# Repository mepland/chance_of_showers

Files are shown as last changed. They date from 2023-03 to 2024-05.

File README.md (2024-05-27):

# chance\_of\_showers
Matthew Epland, PhD

This project provides live water pressure measurements
via a web dashboard running on a Raspberry Pi,
logs the data, and creates time series forecasts of future water pressure.





































## Introduction
Living in a 5th floor walk up in NYC can save you on rent and gym memberships,
but runs the risk of leaving you high and dry when your water pressure gives out!
The pressure delivered from the city's water mains is
_[typically](https://cooperatornews.com/article/dispelling-myths-about-poor-water-pressure)_
sufficient to reach the 6th floor,
with higher buildings needing a booster pump and one of NYC's iconic rooftop
[water towers](https://www.amny.com/real-estate/water-towers-nyc-s-misunderstood-icons-1-6982696).
My building lacks a pump and water tower,
leaving my top floor apartment with _just barely_ satisfactory pressure,
as long as no other units are using water!
As you can see in the data below,
my daytime water pressure is all over the place.
After being stranded soapy and cold halfway through a shower one too many times,
I decided to use my data science and electronics skills to record
the time series of my apartment's hot water pressure
with the goal of forecasting future availability,
and hence `chance_of_showers` was born!

<div align="center">
  <video src="https://github.com/mepland/chance_of_showers/assets/4729931/f3b94d00-fa40-4b0b-8b95-1105d11e7acd"></video>
</div>

## Data Analysis Results
WIP

### Time Series Plots

Below is a sample of the pressure data collected in November 2023.
Clicking the links will open interactive plotly plots, please explore!

#### [Raw analog to digital converter (ADC) values](https://mepland.github.io/chance_of_showers/media/ana_outputs/mean_pressure_value_selected_data.html)

The data acquisition (DAQ) system saves the raw pressure data
from the analog to digital converter (ADC) as an integer between 0 and 65472.
Note that occasionally a water hammer will increase the pressure above its steady state value,
marked by the orange 100% reference line,
with a subsequent decay on the order of 10 minutes.
When water is flowing at the pressure sensor,
the data is shown with an open purple marker.
Using water reduces the pressure slightly under normal conditions,
and abruptly ends overpressure events.

#### [Normalized values](https://mepland.github.io/chance_of_showers/media/ana_outputs/mean_pressure_value_normalized_selected_data.html)

To clean the data before fitting any models,
I rescale the values to 0 and 1 between the steady state extrema.
Any values that are outside the normalization range are capped.

### Overall Pressure Distributions
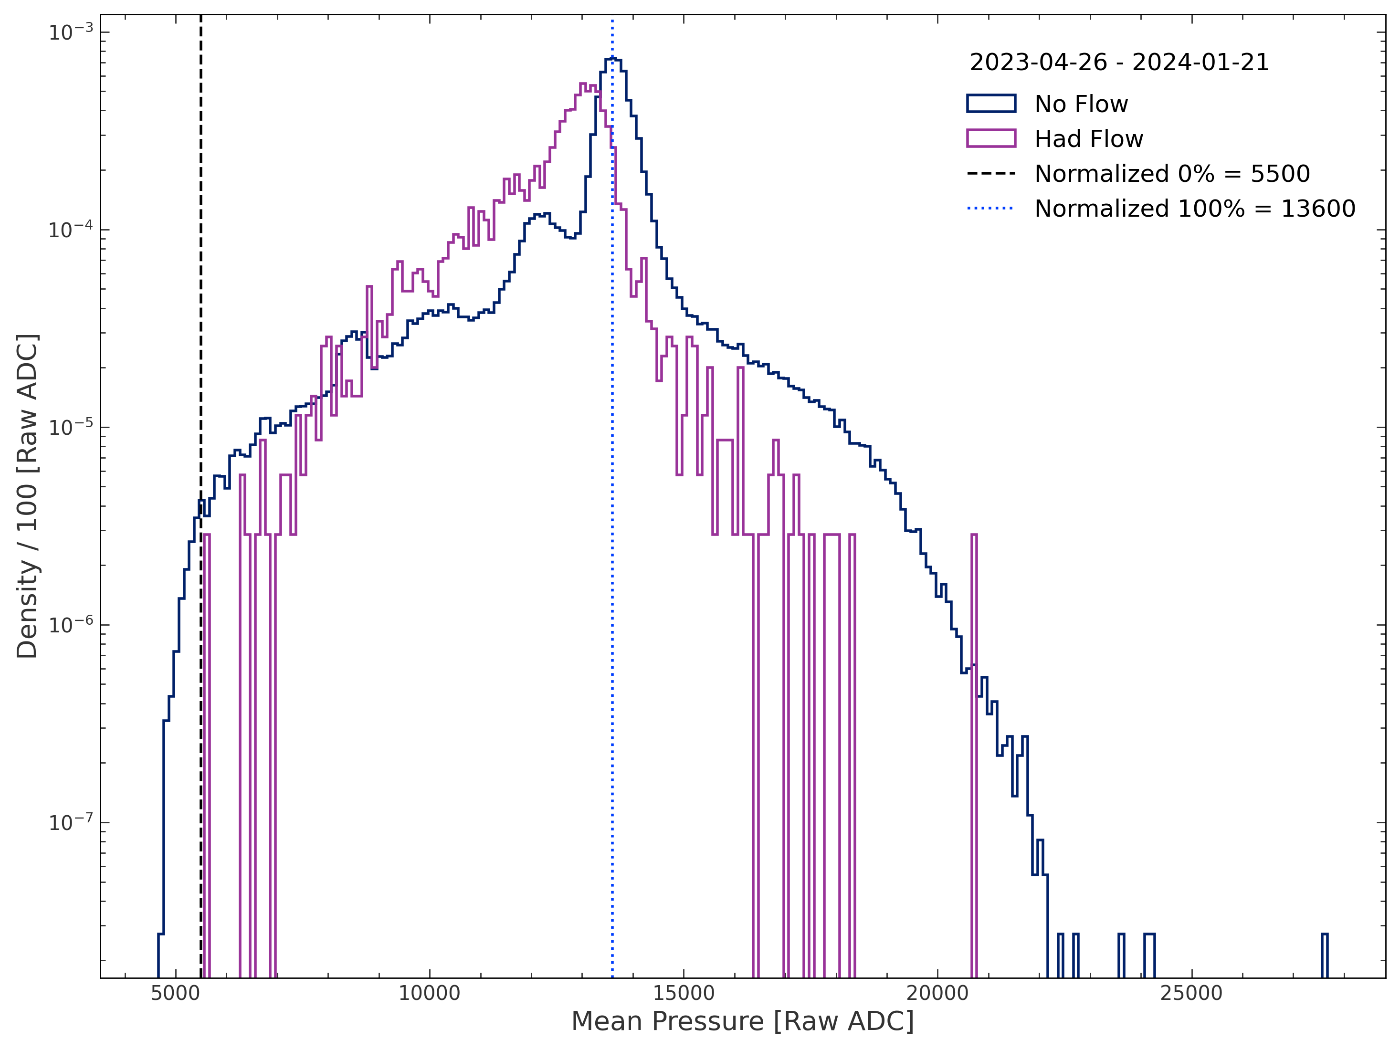
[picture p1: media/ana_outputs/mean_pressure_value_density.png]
Mean Pressure Value Density
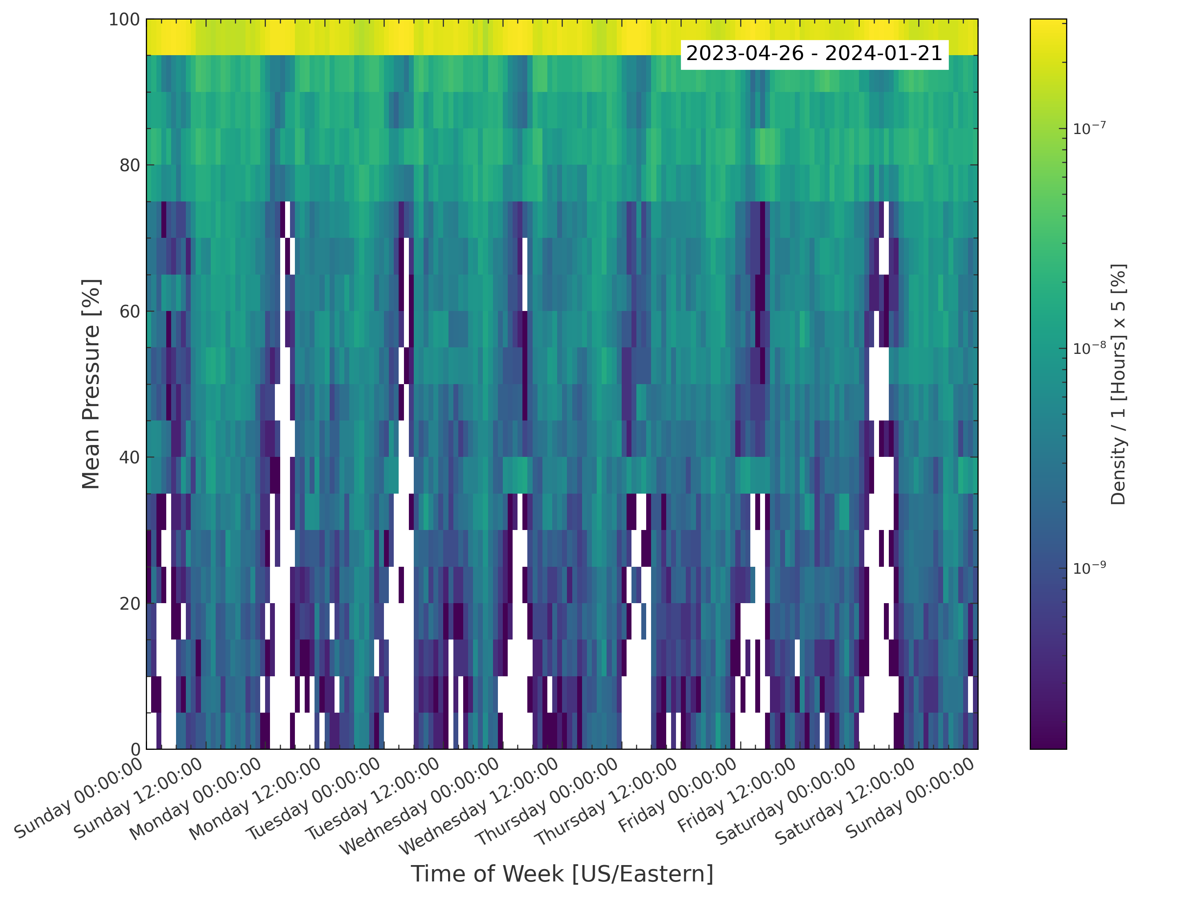
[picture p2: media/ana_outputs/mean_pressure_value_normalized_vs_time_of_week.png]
Mean Pressure Value Normalized vs Time of Week
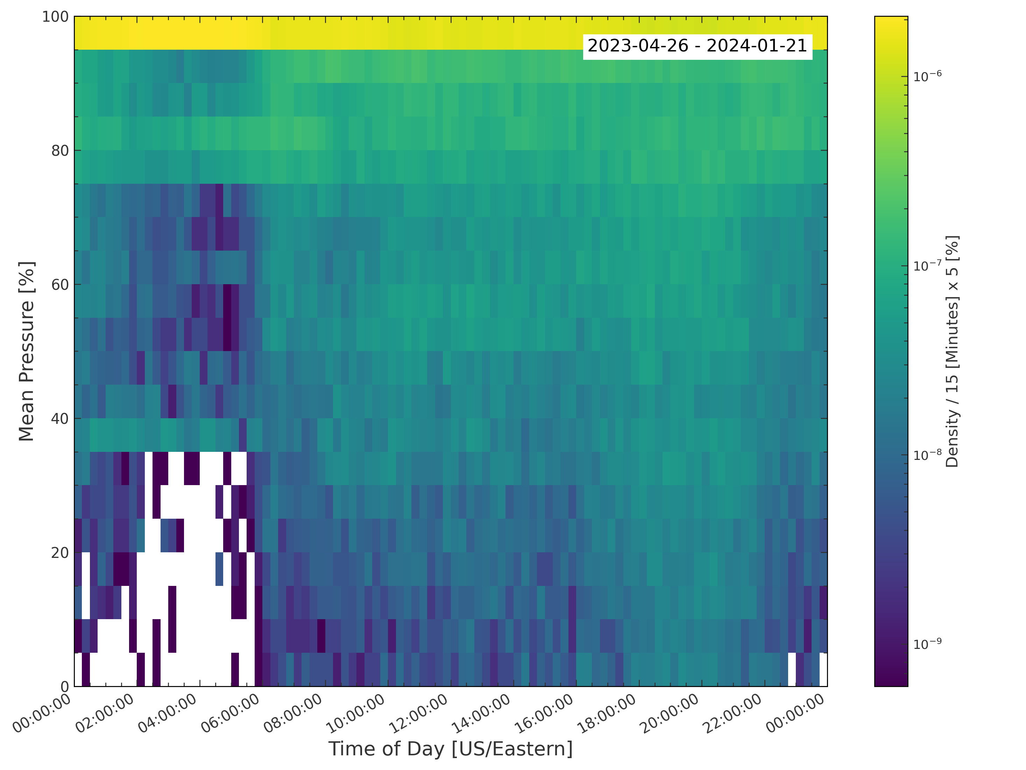
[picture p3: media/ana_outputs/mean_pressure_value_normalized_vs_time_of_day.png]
Mean Pressure Value Normalized vs Time of Day
|  |  |  |
| :---: | :---: | :---: |

### Prophet Results
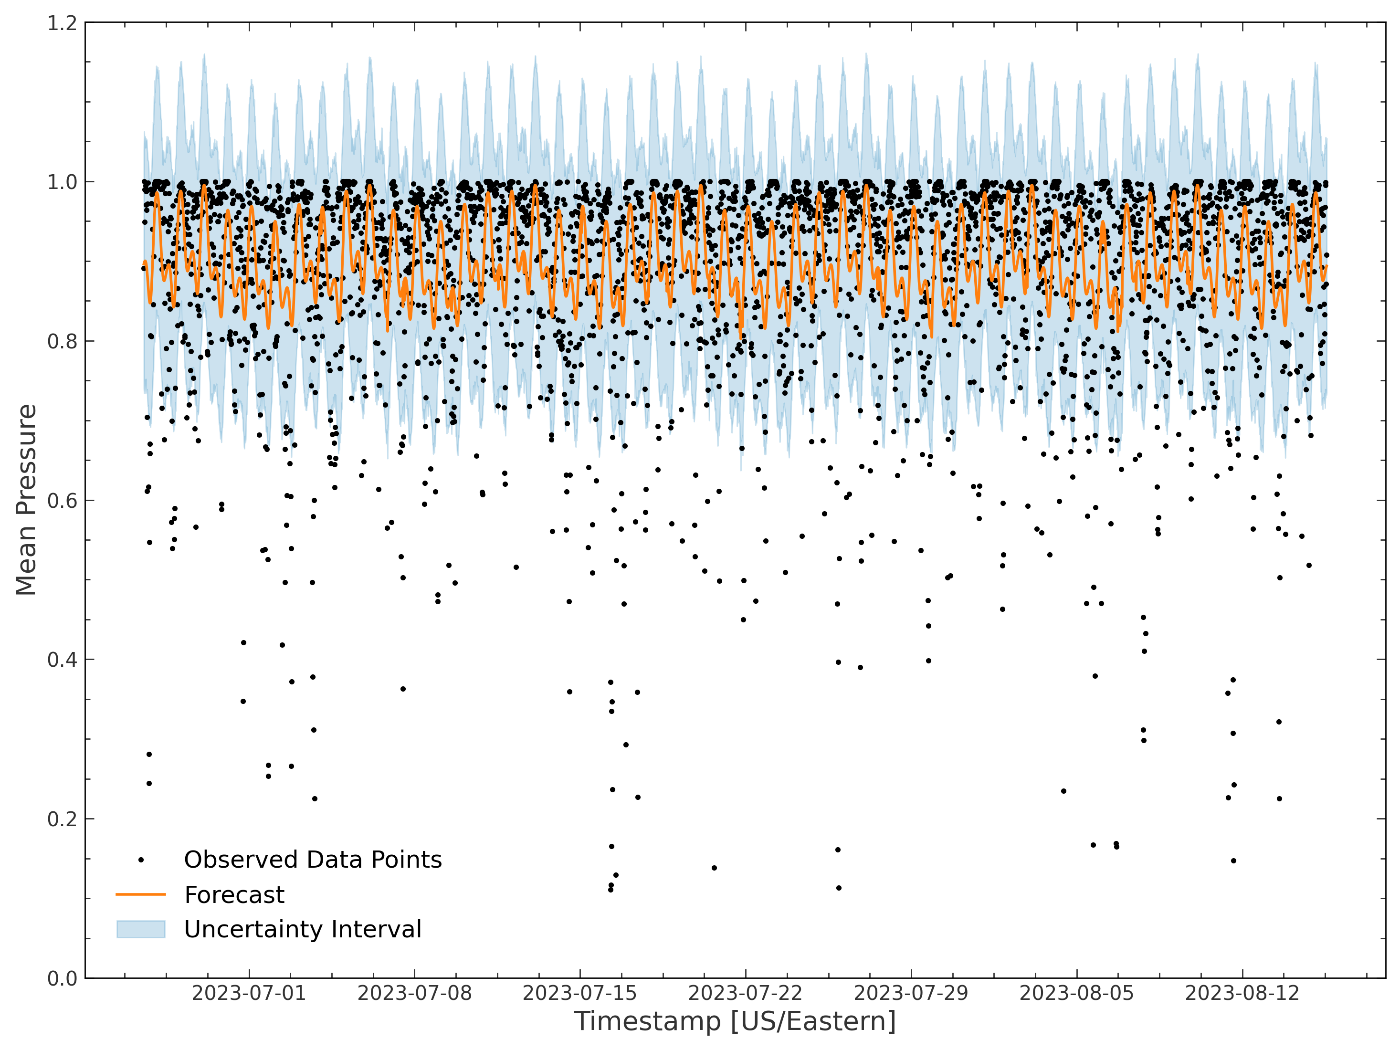
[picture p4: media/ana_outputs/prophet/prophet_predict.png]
Prophet Predict
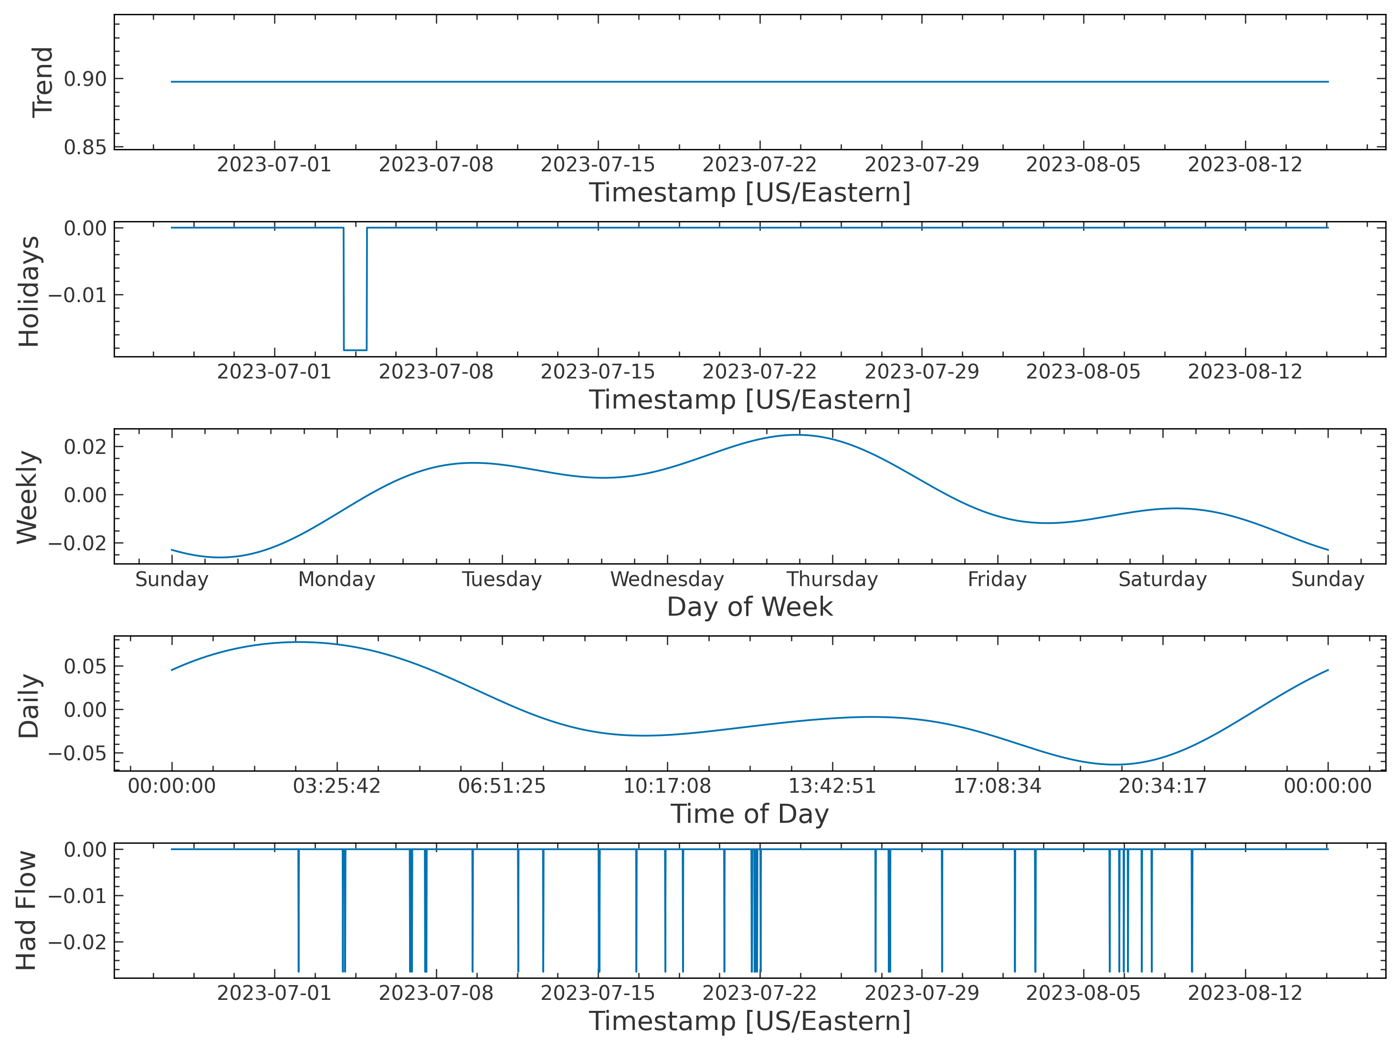
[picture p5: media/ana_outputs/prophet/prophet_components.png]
Prophet Components
|  |  |
| :---: | :---: |
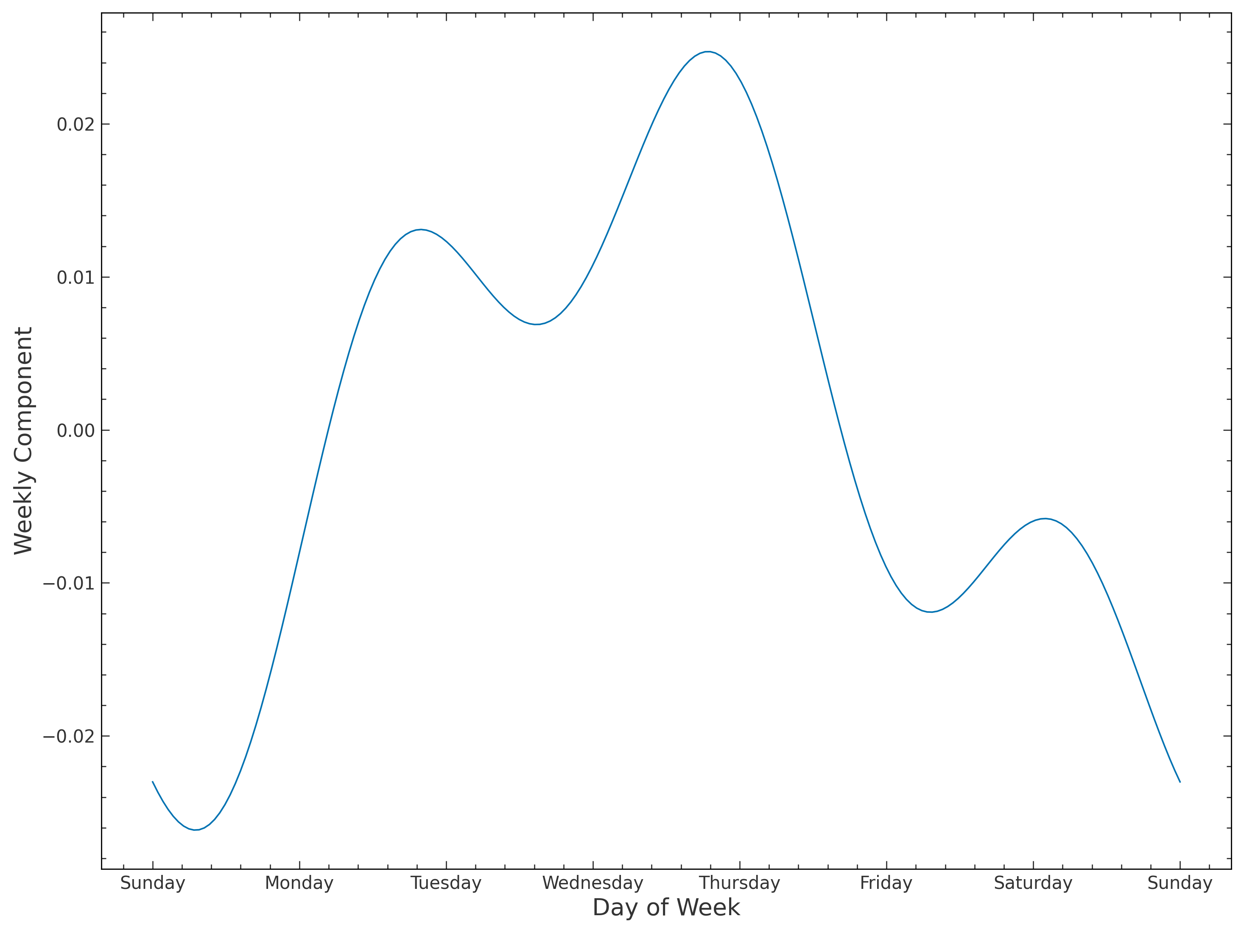
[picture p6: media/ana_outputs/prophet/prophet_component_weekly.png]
Prophet Components Weekly
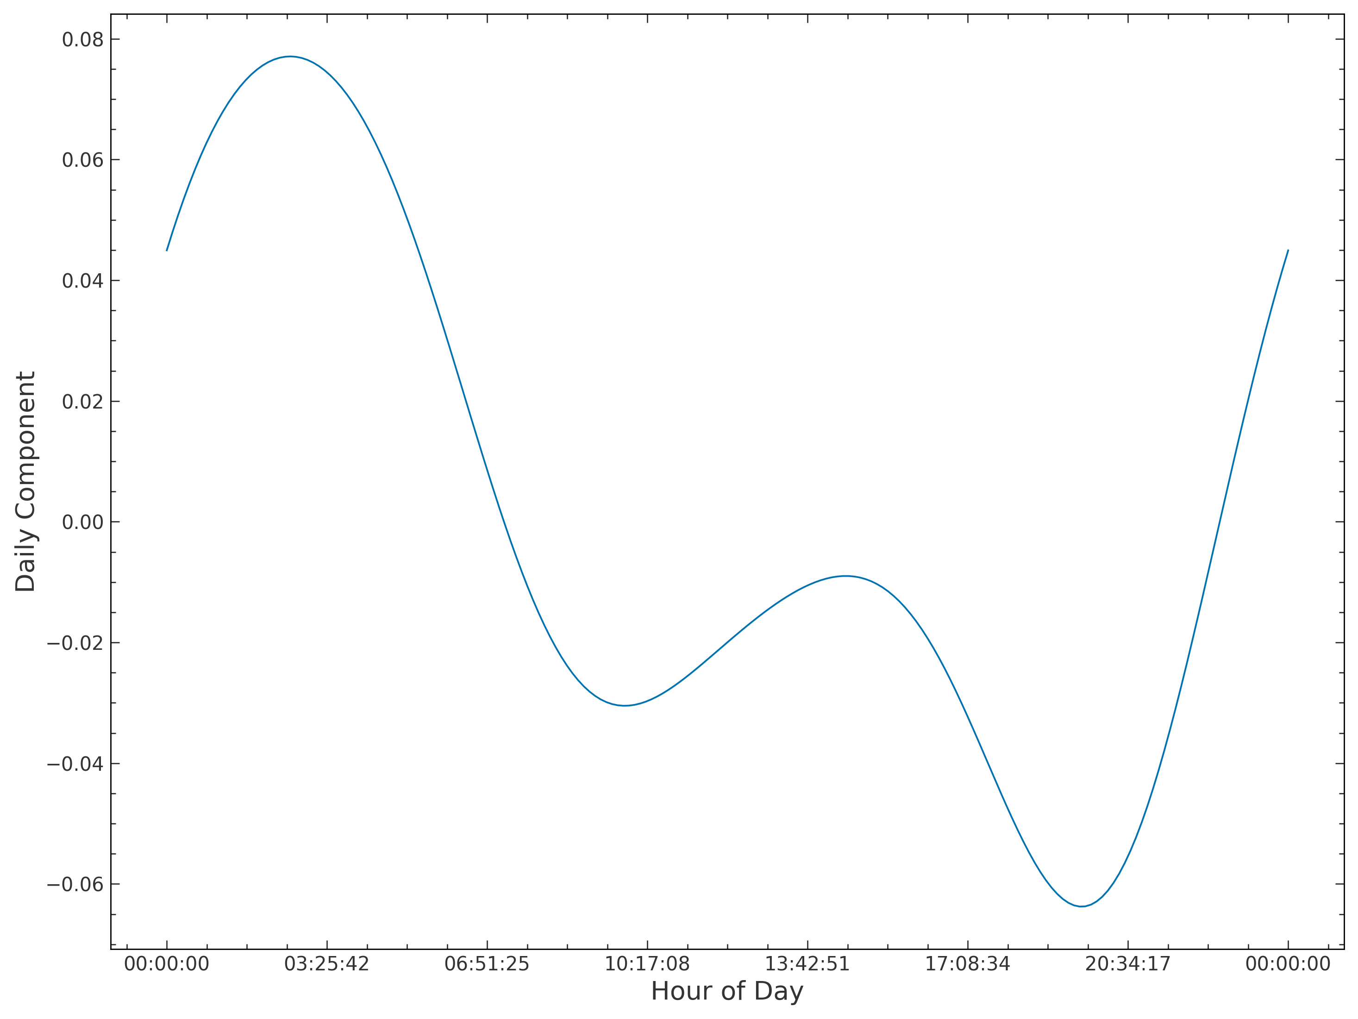
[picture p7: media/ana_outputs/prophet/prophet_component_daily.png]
Prophet Components Daily
|  |  |

## Hardware

### Bill of Materials
Here is a list of the components I used in my build.
With suitable alterations, the project could definitely be carried out with a wide array of other
sensors, single board computers or microcontrollers, plumbing supplies, etc.

#### Electronics

* [Raspberry Pi 4 Model B 2 GB](https://www.raspberrypi.com/products/raspberry-pi-4-model-b)
  * [USB C Power Supply](https://www.raspberrypi.com/products/type-c-power-supply)
  * [Micro SD Card](https://www.amazon.com/gp/product/B09TQS634Y)
* [8-Channel 10-Bit ADC with SPI Interface - MCP3008](https://www.digikey.com/en/products/detail/microchip-technology/MCP3008-I-P/319422)
* [DFRobot Gravity Water Pressure Sensor - SEN0257](https://wiki.dfrobot.com/Gravity__Water_Pressure_Sensor_SKU__SEN0257)
* [Water Flow Hall Effect Sensor Switch - YWBL-WH](https://www.amazon.com/Interface-Electromagnetic-Flowmeter-Industrial-Accessory/dp/B08B1NG4FZ)
* [1 kΩ and 10 kΩ Resistors](https://www.amazon.com/gp/product/B072BL2VX1)
* 830 Point Breadboard and Dupont Jumper Wires - [Included in GPIO Kit](https://www.amazon.com/gp/product/B08B4SHS18)

#### Plumbing

* [1/2" NPT 3 Way Tee Connector](https://www.amazon.com/Stainless-Diverter-Movable-Flexible-Connector/dp/B09MT39487)
* [Faucet Connector Hose, 3/8" Female Compression Thread to 1/2" Female NPT Thread - B1F09](https://www.amazon.com/gp/product/B000BQWNP8)
* [Adapter, 3/8" Male NPT to 1/2" Female NPT](https://www.amazon.com/gp/product/B07LD3GN4X/ref=ppx_od_dt_b_asin_title_s01)
* [Adapter, 1/2" Male NPT to G1/4" Female - ADT-N12M-G14F](https://koolance.com/threading-adapter-npt-1-2-male-to-g-1-4-female-adt-n12m-g14f)
* [PTFE (Teflon) Thread Seal Tape](https://www.amazon.com/DOPKUSS-Plumbers-Sealant-Waterproof-Inches/dp/B095YCMHNX)

#### Optional Components

* [I2C OLED Display](https://www.amazon.com/dp/B01MRR4LVE)
* [Geekworm Baseplate](https://www.amazon.com/gp/product/B07WCBXFD3)
* Wiring
  * [GPIO Extension Cable Kit](https://www.amazon.com/gp/product/B08B4SHS18)
  * [Breadboard Jumper Wires](https://www.amazon.com/gp/product/B07CJYSL2T)
  * [Clip to Dupont Jumper Wires](https://www.amazon.com/gp/product/B08M5GNY47)
* Cooling
  * [Heatsink - Geekworm P165-B](https://www.amazon.com/gp/product/B08N5VZN8R)
  * [Fan - Noctua NF-A4x20 5V PWM 4-Pin 40x20mm](https://www.amazon.com/gp/product/B071FNHVXN)
  * [2x20 Pin Header Kit](https://www.amazon.com/gp/product/B08GC18NMK) to clear heatsink
  * One [M3 Screw](https://www.amazon.com/gp/product/B01I74TTWU) to attach fan to heatsink
  * Four [M2.5 Screws](https://www.amazon.com/HELIFOUNER-Screws-Washers-Kit-Threaded/dp/B0BKSGC86F)
to attach heatsink to Pi and baseplate

### Circuit Diagram
The circuit diagram for this implementation
is provided as a [KiCad](https://www.kicad.org) schematic
[here](circuit_diagram/circuit_diagram.kicad_sch).

Circuit Diagram

### Photos
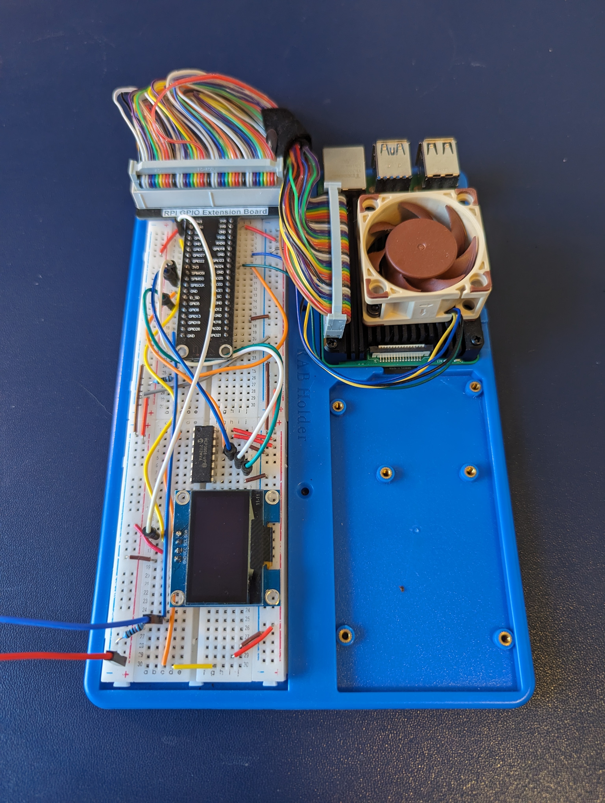
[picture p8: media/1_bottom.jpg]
Bottom
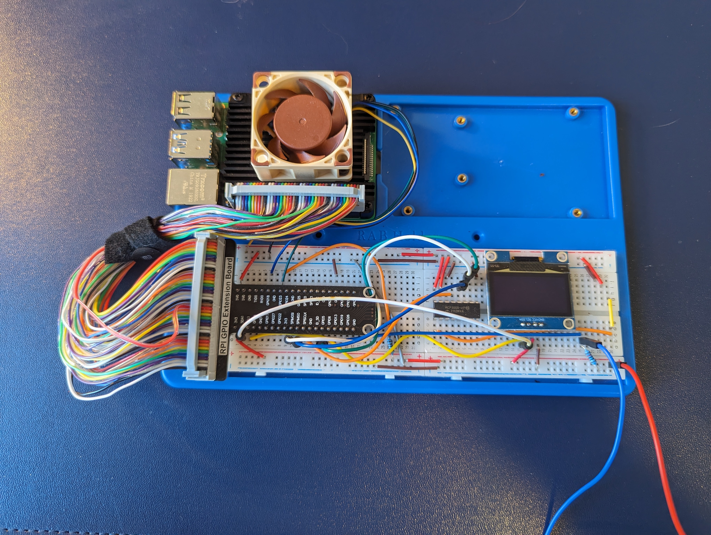
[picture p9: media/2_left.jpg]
Left
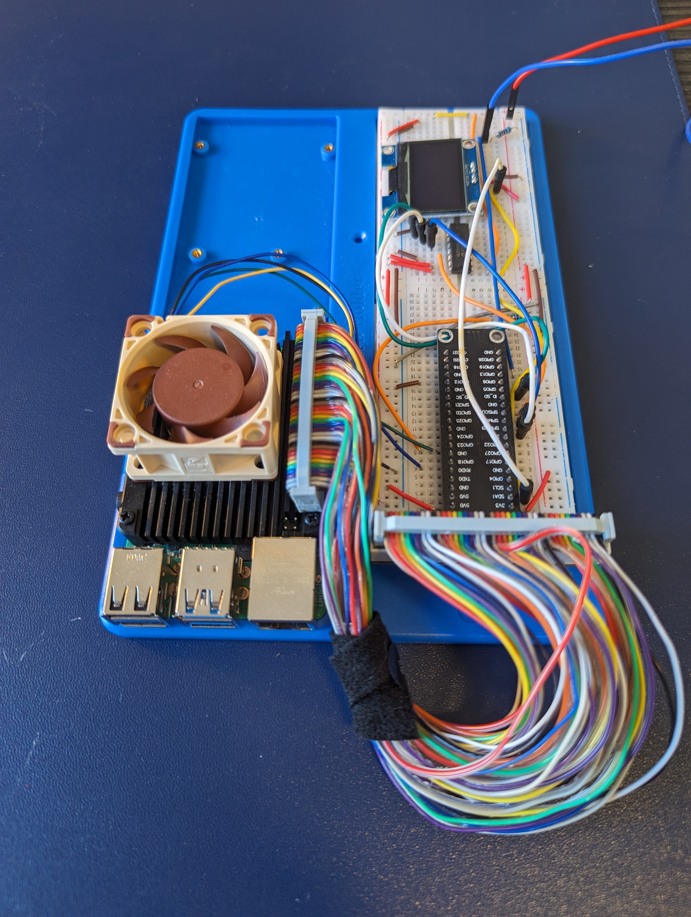
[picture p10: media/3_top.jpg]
Top
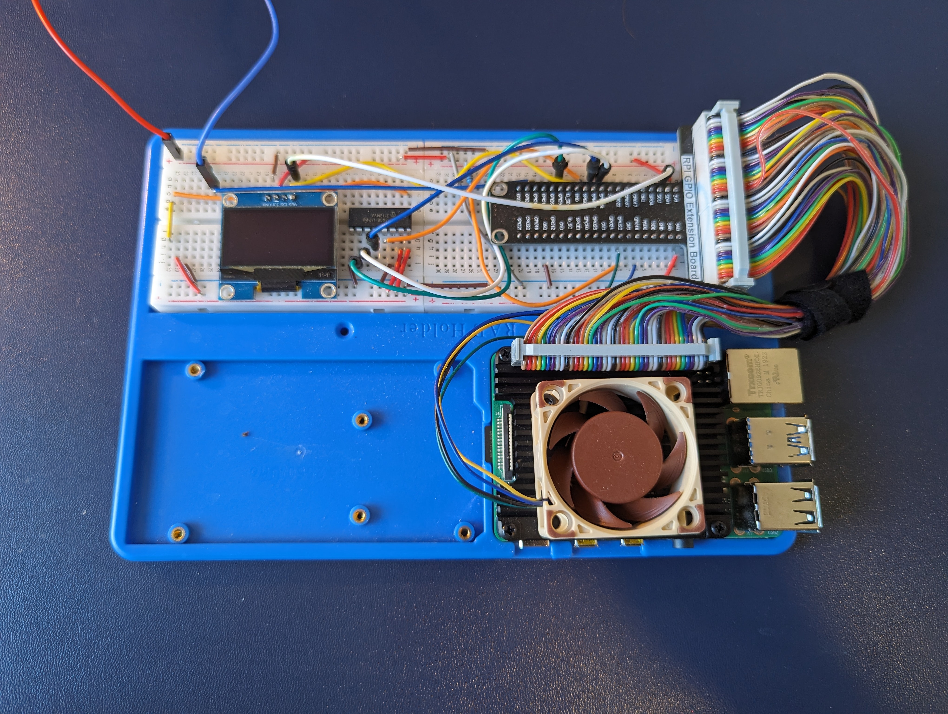
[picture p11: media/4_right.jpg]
Right
|  |  |  |  |
| :---: | :---: | :---: | :---: |
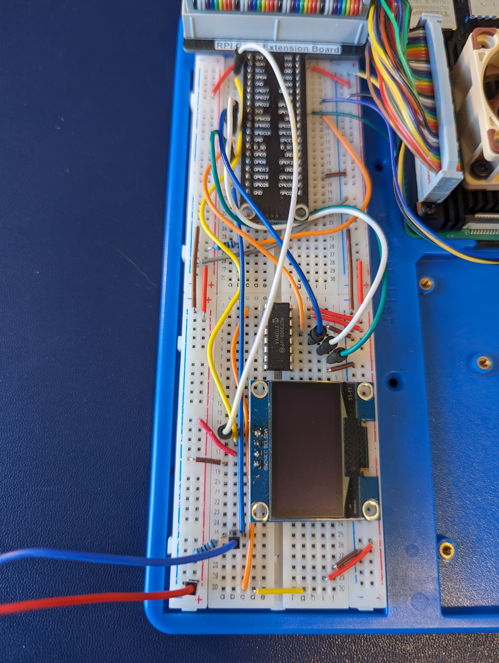
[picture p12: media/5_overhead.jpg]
Overhead
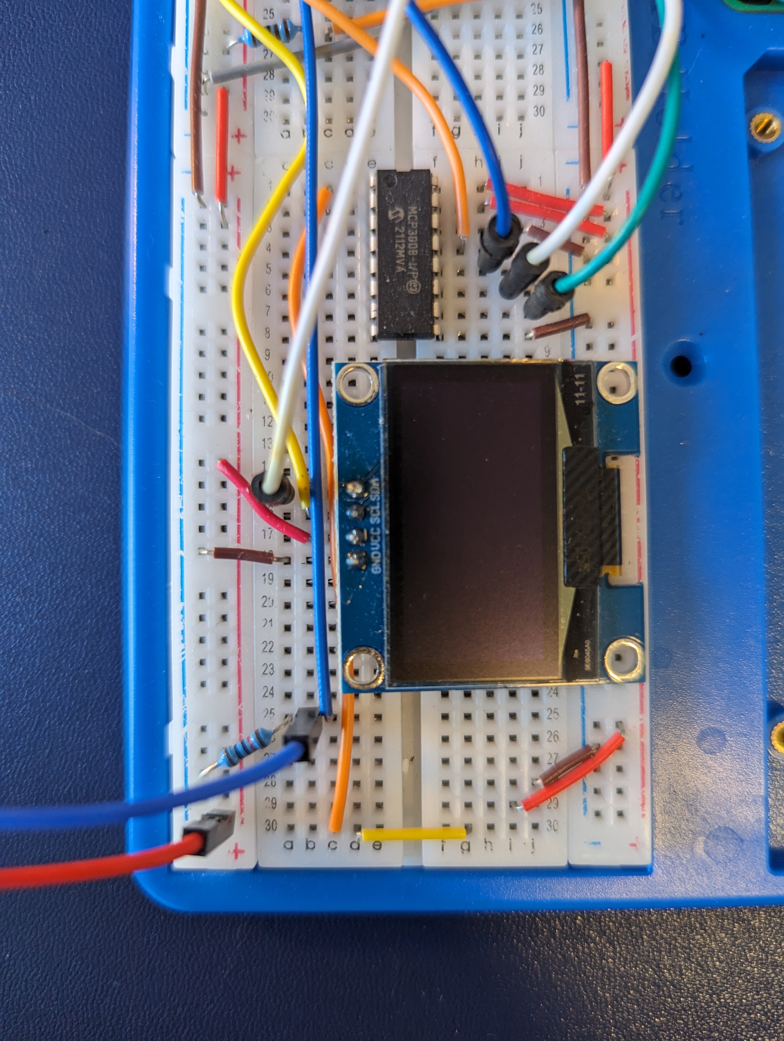
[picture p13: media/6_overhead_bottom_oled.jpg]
Overhead Bottom OLED
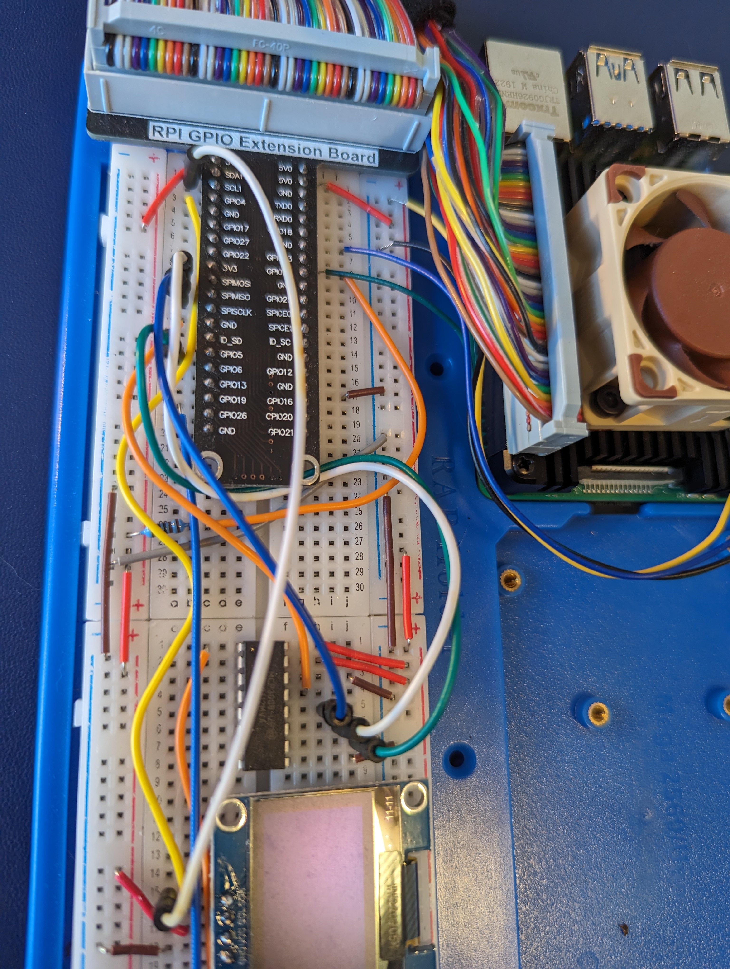
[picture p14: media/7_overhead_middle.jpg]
Overhead Middle
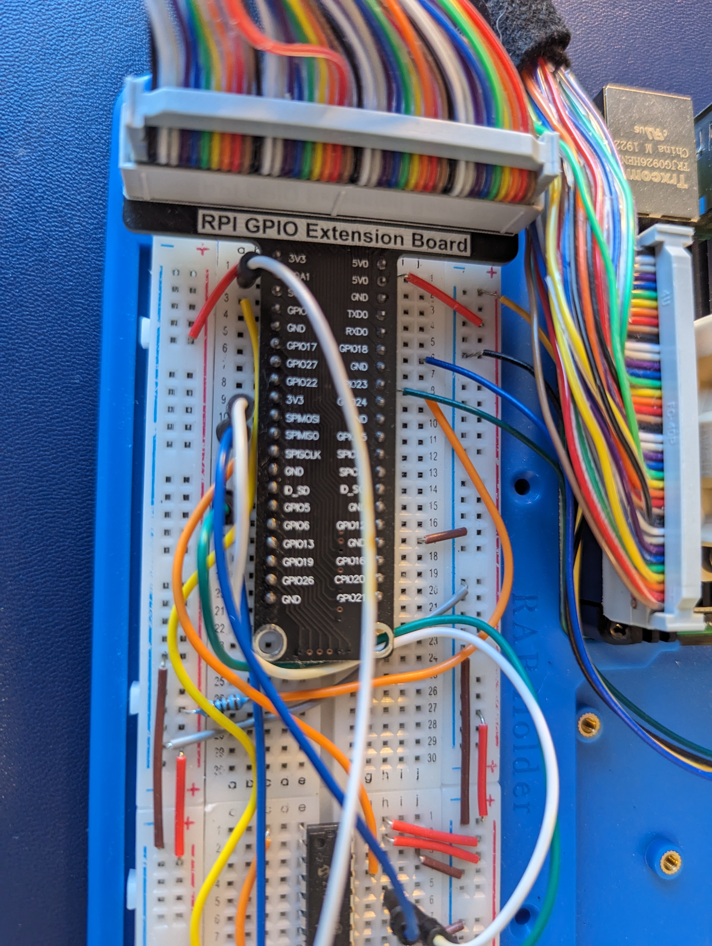
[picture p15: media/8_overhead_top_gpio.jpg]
Overhead Top GPIO
|  |  |  |  |
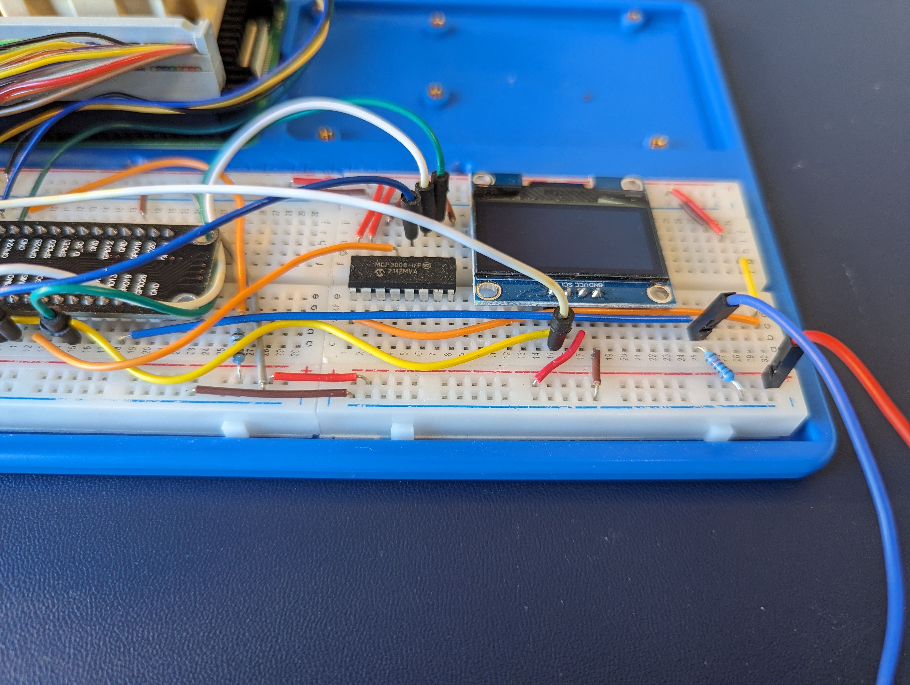
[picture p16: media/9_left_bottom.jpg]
Left Bottom
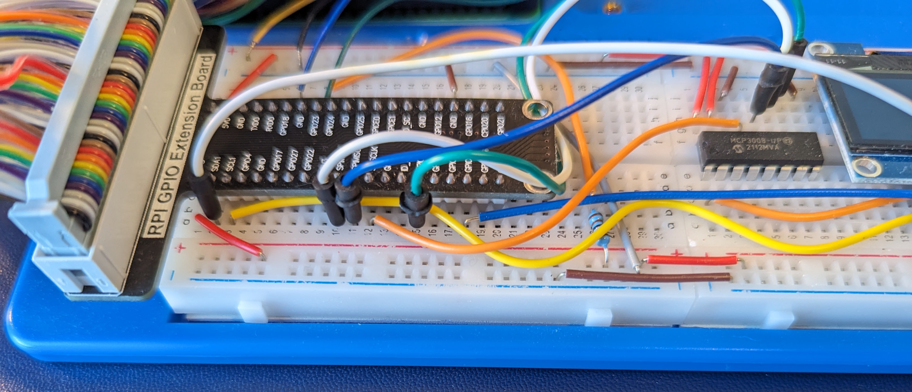
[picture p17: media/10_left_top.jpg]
Left Top
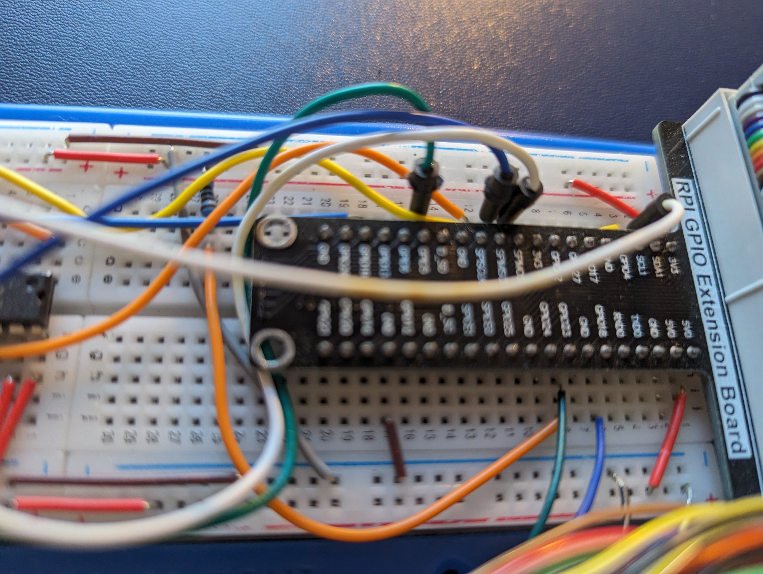
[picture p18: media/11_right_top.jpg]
Right Top
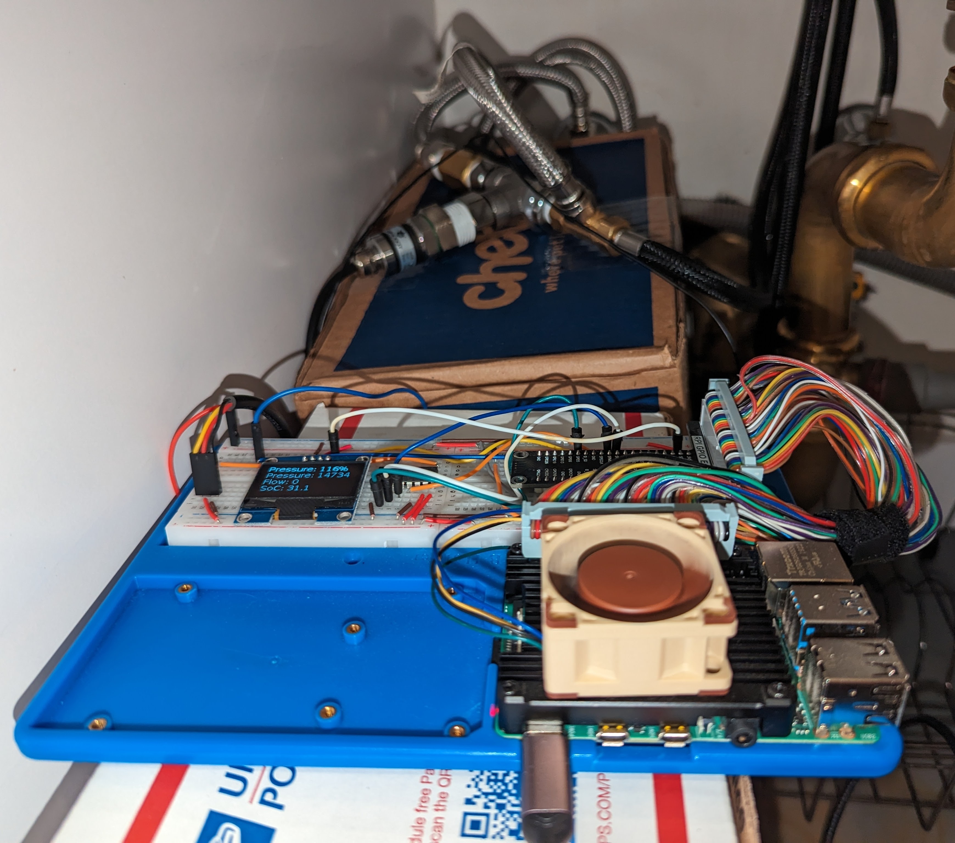
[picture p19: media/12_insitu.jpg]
In Situ
|  |  |  |  |
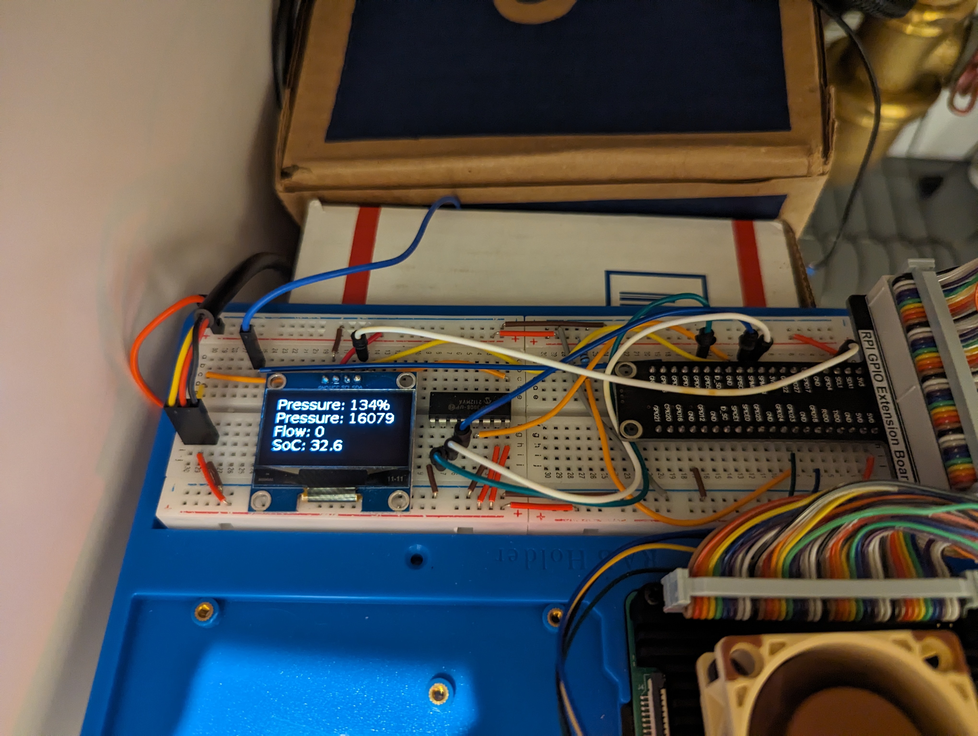
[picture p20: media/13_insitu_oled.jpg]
In Situ OLED
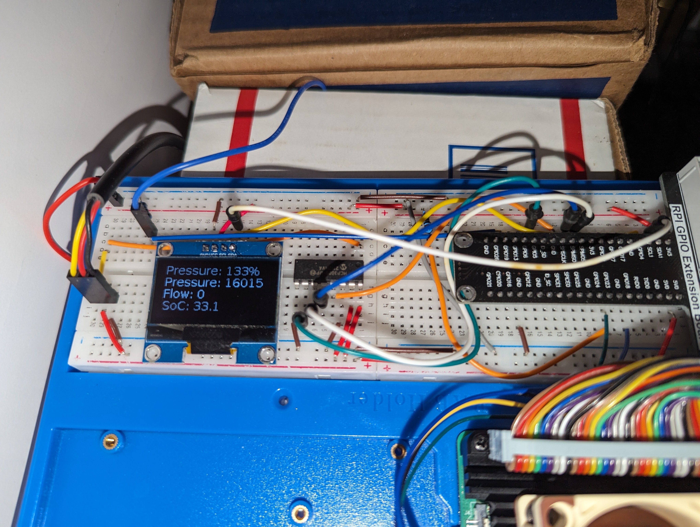
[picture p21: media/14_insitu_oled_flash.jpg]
In Situe OLED (Flash)
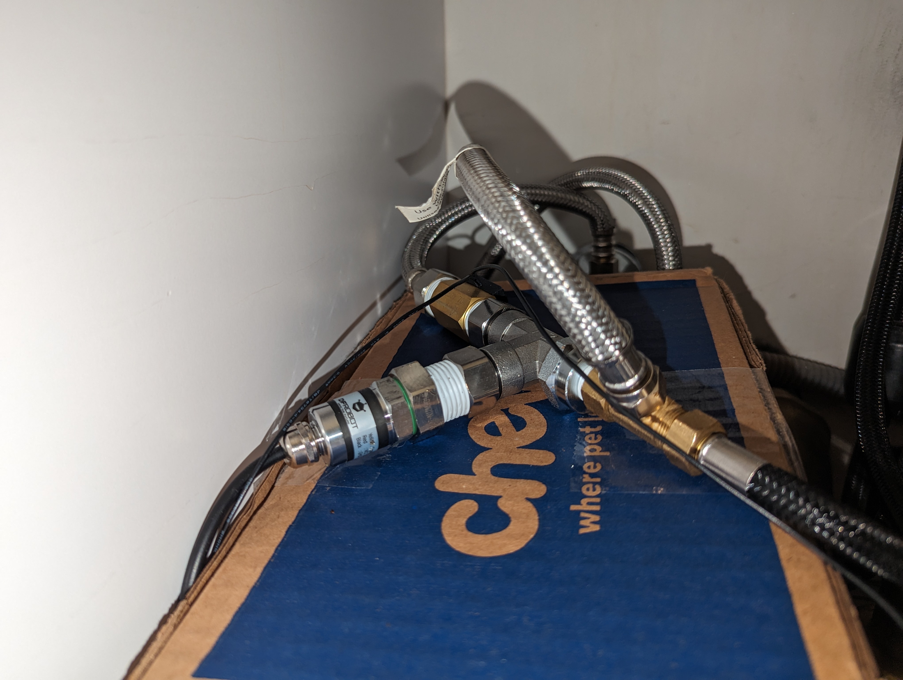
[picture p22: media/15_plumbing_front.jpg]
Plumbing Front
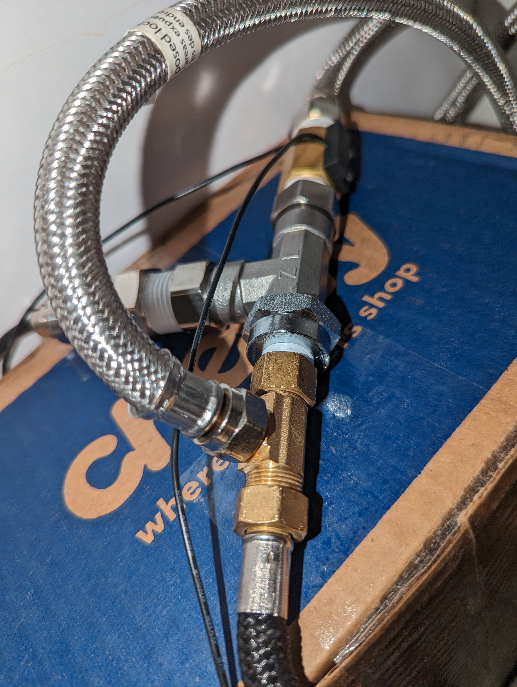
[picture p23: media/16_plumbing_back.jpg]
Plumbing Back
|  |  |  |  |

## Data Acquisition (DAQ)

The DAQ system recorded 95.4% of possible data points overall,
and 99.870% since implementing the cron job heartbeat monitoring.

### Launching the DAQ Script
The provided [`start_daq`](daq/start_daq) bash script
will start the [`daq.py`](daq/daq.py) and [`fan_control.py`](fan_control/fan_control.py)
scripts in new `tmux` windows.
You will need to update the `pkg_path` variable in `start_daq` per your installation location.

```bash
source daq/start_daq
```

### Opening the Web Dashboard
If `daq: {display_web: true}` is set in [`config.yaml`](config.yaml),
the local IP address and port of the dashboard will be logged on DAQ startup.
Open this link in your browser to see the live dashboard, as shown in the introduction.

### Setting up cron Jobs
Jobs to restart the DAQ on boot and every 30 minutes,
as well as send heartbeat API calls - see below,
are provided in the [`cron_jobs.txt`](daq/cron_jobs.txt) file.
Note that loading this file with `crontab` will overwrite **any** current cron jobs,
so check your existing settings first with `crontab -l`!

```bash
crontab -l

crontab daq/cron_jobs.txt
```

You can verify the cron jobs are running as expected with:

```bash
grep CRON /var/log/syslog | grep $LOGNAME
```

### Heartbeat Monitoring
You can use the provided [`heartbeat`](daq/heartbeat) bash script to send heartbeat API calls
for the DAQ script to [healthchecks.io](https://healthchecks.io) for monitoring and alerting.
[Configure your alert online at healthchecks.io](https://healthchecks.io/docs/configuring_checks),
and then run the below commands to setup a `secrets.json` file with your alert's `uuid`.
You will need to update the `pkg_path` variable in `heartbeat` per your installation location.
The provided `cron_jobs.txt` will setup a cron job
to send the heartbeat on the 15 and 45 minute of each hour.

```bash
sudo apt install -y jq
echo -e "{\n\t\"chance_of_showers_heartbeat_uuid\": \"YOUR_UUID_HERE\"\n}" > secrets.json
source daq/heartbeat
```

The `heartbeat` script has also been setup to backup
the `daq/raw_data` and `daq/saved_data` directories to
`backup_path="/media/usb_drive/daq_backup"`.
Please configure `backup_path` to fit your path, or comment out the `rsync` lines to turn them off.
Regular backups of the data to a separate drive are helpful as Raspberry Pis
have been known to corrupt their SD cards due to power loss or excessive writes.

### Combining Raw DAQ Files

Raw CSV files can be combined into convenient Parquet files
prior to analysis with the [`etl.py`](daq/etl.py) script.
If the script crashes, you may need to manually repair
any lines in the CSV files corrupted due to power losses.
Polars should generate error messages indicating
the corrupt datetime to help you locate the problematic file and line.

```bash
python daq/etl.py
```

## Bayesian Optimization

To optimize the many hyperparameters present in this project,
both of the individual forecasting models themselves as well as how the data is prepared,
[Bayesian optimization](https://github.com/mepland/data_science_notes)
was used to efficiently sample the parameter space.
The functions needed to run Bayesian optimization
are located in [`bayesian_opt.py`](utils/bayesian_opt.py),
and make use of the
[`bayesian-optimization`](https://github.com/bayesian-optimization/BayesianOptimization) library.

Unfortunately, actually running the optimization over GPU accelerated models
is not as simple as calling the `run_bayesian_opt()` function.
I have been unable to successfully detach the training of one GPU accelerated model
from the next when training multiple models in a loop.
The second training session will still have access to the tensors of the first,
leading to out of GPU memory errors, even when
[using commands like `gc.collect()` and `torch.cuda.empty_cache()`](https://stackoverflow.com/questions/70508960/how-to-free-gpu-memory-in-pytorch).
The `torch` models created by `darts` are very convenient,
but do not provide as much configurability as building your own `torch` model from scratch,
leaving me unable to fix this issue in a clean way.

To work around the GPU memory issues, a shell script,
[`start_bayesian_opt`](ana/start_bayesian_opt), is used to repeatedly call `run_bayesian_opt()`
via the [`bayesian_opt_runner.py`](ana/bayesian_opt_runner.py) script.
In this way each model is trained in its own Python session,
totally clearing memory between training iterations.
A signed pickle file is used to quickly load the necessary data and settings on each iteration.
Instructions for running the whole Bayesian optimization workflow are provided below.

Some hyperparameter points chosen for testing by the optimizer result in crashes during training,
either due to memory limitations, or invalid parameter combinations that slip by pre-run checks.
In most cases these exceptions can be caught within Python,
allowing the point to be automatically logged as having the worst possible `BAD_TARGET = -999.0`.
However, the Python process itself is occasionally killed
by the operating system with an uncatchable `SIGKILL` signal,
likely due to a request for too much memory.
Resuming the run will only result in repeated crashes on the same point as it is never written to disk.
Rather than rework the `bayesian-optimization` library to pre-register points before optimization,
a [`manual_bad_point.py`](ana/manual_bad_point.py) script is included
to easily log the few such points by hand.

### Running Bayesian Optimization

1. Create the input `parent_wrapper.pickle` file for `bayesian_opt_runner.py`
via the `exploratory_ana.py` notebook.
2. Configure the run in `start_bayesian_opt` and `bayesian_opt_runner.py`.
3. Run the shell script, logging outputs to disk via:
    * Log any bad points that are killed by the operating system
with `manual_bad_point.py` and resume the search.

```bash
./ana/start_bayesian_opt 2>&1 | tee ana/models/bayesian_optimization/bayesian_opt.log
```

## Dev Notes

### Data Analysis Setup - Installing CUDA and PyTorch

1. Find the supported CUDA version (`11.8.0`) for the current release of PyTorch (`2.0.1`) [here](https://pytorch.org/get-started/locally).
2. Install CUDA following the steps for the proper version and target platform [here](https://developer.nvidia.com/cuda-toolkit-archive).
3. Update the poetry `pytorch-gpu-src` source to point to the correct PyTorch version in [`pyproject.toml`](pyproject.toml).
    * This is in place of `pip install --index-url=...` as provided by the [PyTorch installation instructions](https://pytorch.org/get-started/locally).
4. Install the poetry `ana` group with `make setupANA`.
    * This will install `pytorch`, along with the other necessary packages.
5. Check that PyTorch and CUDA are correctly configured with the following `python` commands:

```python
import torch

if torch.cuda.is_available():
    print("CUDA is available")
    print(f"Device name: {torch.cuda.get_device_name(torch.cuda.current_device())}")
else:
    print("CUDA IS NOT AVAILABLE!")
```

### DAQ Setup - Installing Python 3.11 on Raspbian
If `python 3.11` is not available in your release of Raspbian,
you can compile it from source following the instructions [here](https://aruljohn.com/blog/python-raspberrypi),
but will also need to [install the sqlite extensions](https://stackoverflow.com/a/24449632):

<!-- markdownlint-disable MD013 -->
```bash
cd /usr/src/
sudo wget https://www.python.org/ftp/python/3.11.4/Python-3.11.4.tgz
sudo tar -xzvf Python-3.11.4.tgz
cd Python-3.11.4/
sudo apt update && sudo apt full-upgrade -y
sudo apt install -y build-essential libbz2-dev libc6-dev libexpat1-dev libffi-dev libgdbm-dev liblzma-dev libncurses5-dev libnss3-dev libsqlite3-dev libssl-dev lzma pkg-config zlib1g-dev
sudo apt autoremove -y
sudo apt update && sudo apt full-upgrade -y
./configure --enable-optimizations --enable-loadable-sqlite-extensions
sudo make altinstall

# Should be Python 3.11.4 with your compile info
/usr/local/bin/python3.11 -VV

# Link binary
sudo rm /usr/bin/python
sudo rm /usr/bin/python3
sudo ln -s /usr/local/bin/python3.11 /usr/bin/python
sudo ln -s /usr/local/bin/python3.11 /usr/bin/python3

# Should match /usr/local/bin/python3.11 -VV
python -VV
```

#### Additional DAQ Dependencies
To finish setting up the DAQ system you must also:

* Install `tmux`, which is not included in Raspbian by default.
`tmux` is used to control multiple terminal sessions in [`start_daq`](daq/start_daq).
* Install `pigpio`, which is not included in Raspbian Lite, i.e. headless, installations.
`pigpio` is necessary to interface with the GPIO ports and must also be enabled via a [daemon](https://gpiozero.readthedocs.io/en/latest/remote_gpio.html)
* Enable SPI, I2C, and Remote GPIO via `raspi-config`.
* Prevent the [WiFi from powering off](https://desertbot.io/blog/headless-raspberry-pi-4-ssh-wifi-setup-64-bit-mac-windows).
* It is recommended to [install](https://pimylifeup.com/raspberry-pi-log2ram) [`log2ram`](https://github.com/azlux/log2ram) to avoid unnecessary writes to the SD card, prolonging the card's lifetime.

```bash
# Install tmux and pigpio
sudo apt-get install -y tmux pigpio

# Enable SPI, I2C, and Remote GPIO
sudo raspi-config

# Setup pigpio daemon
sudo systemctl enable pigpiod

# Prevent the WiFi from powering off
# Above the line that says exit 0 insert `/sbin/iw wlan0 set power_save off` and save the file
sudo vi /etc/rc.local

# Install log2ram
echo "deb [signed-by=/usr/share/keyrings/azlux-archive-keyring.gpg] http://packages.azlux.fr/debian/ bullseye main" | sudo tee /etc/apt/sources.list.d/azlux.list
sudo wget -O /usr/share/keyrings/azlux-archive-keyring.gpg https://azlux.fr/repo.gpg
sudo apt update && sudo apt full-upgrade -y
sudo apt install -y log2ram
```
<!-- markdownlint-enable MD013 -->

### Installing Dependencies with Poetry
Install `poetry` following the [instructions here](https://python-poetry.org/docs#installation).

```bash
curl -sSL https://install.python-poetry.org | python3 -
```

Then install the `python` packages needed for this installation. Groups include:

* `daq` for packages needed to run the DAQ script on a Raspberry Pi, optional
* `web` for packages needed to run the live dashboard from the DAQ script, optional
* `ana` for analysis tools, optional
* `dev` for continuous integration (CI) and linting tools

```bash
poetry install --with daq,web
```

or

```bash
poetry install --with ana
```

### Setting up pre-commit
It is recommended to use the [`pre-commit`](https://pre-commit.com) tool
to automatically check your commits locally as they are created.
You should just need to [install the git hook scripts](https://pre-commit.com/#3-install-the-git-hook-scripts),
see below, after installing the `dev` dependencies.
This will run the checks in [`.pre-commit-config.yaml`](.pre-commit-config.yaml)
when you create a new commit.

```bash
pre-commit install
```

### Installing Non-Python Based Linters
Markdown is linted using [`markdownlint-cli`](https://github.com/igorshubovych/markdownlint-cli),
JavaScript by [`standard`](https://github.com/standard/standard),
and HTML, SCSS, CSS, and TOML by [`prettier`](https://prettier.io).
You can install these JavaScript-based linters globally with:

```bash
sudo npm install --global markdownlint-cli standard prettier
sudo npm install --global --save-dev --save-exact prettier-plugin-toml
```

Shell files are linted using [`shellcheck`](https://github.com/koalaman/shellcheck)
and [`shfmt`](https://github.com/mvdan/sh).
Follow the linked installation instructions for your system.
On Fedora they are:

```bash
sudo dnf install ShellCheck shfmt
```

### Using the Makefile
A [`Makefile`](Makefile) is provided for convenience,
with commands to setup the DAQ and analysis environments,
`make setupDAQ` and `make setupANA`,
as well run CI and linting tools,
e.g. `make black`, `make pylint`, `make pre-commit`.

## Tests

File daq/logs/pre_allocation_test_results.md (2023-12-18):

# DAQ Pre-allocation Tests
Below are the tails of log files for complete weeks, without any web logging messages.

## Pre-allocated Results
`daq_2023-11-12-05-00-16.log` and prior use pre-allocated array variables, and have less memory usage.

<!-- markdownlint-disable MD013 -->
```bash
==> daq_2023-10-01-04-00-16.log <==
2023-10-07 23:01:00 UTC [daq     ] [Thread-6 (] [INFO    ] RAM Available: 1.7 GB, Used: 229.7 MB, Percent: 15.80%
2023-10-07 23:31:00 UTC [daq     ] [Thread-6 (] [INFO    ] RAM Available: 1.7 GB, Used: 229.6 MB, Percent: 15.80%
2023-10-08 00:01:00 UTC [daq     ] [Thread-6 (] [INFO    ] RAM Available: 1.7 GB, Used: 229.5 MB, Percent: 15.80%
2023-10-08 00:31:00 UTC [daq     ] [Thread-6 (] [INFO    ] RAM Available: 1.7 GB, Used: 230.6 MB, Percent: 15.80%
2023-10-08 01:01:00 UTC [daq     ] [Thread-6 (] [INFO    ] RAM Available: 1.7 GB, Used: 231.1 MB, Percent: 15.90%
2023-10-08 01:31:00 UTC [daq     ] [Thread-6 (] [INFO    ] RAM Available: 1.7 GB, Used: 231.0 MB, Percent: 15.90%
2023-10-08 02:01:00 UTC [daq     ] [Thread-6 (] [INFO    ] RAM Available: 1.7 GB, Used: 230.8 MB, Percent: 15.80%
2023-10-08 02:31:00 UTC [daq     ] [Thread-6 (] [INFO    ] RAM Available: 1.7 GB, Used: 231.0 MB, Percent: 15.90%
2023-10-08 03:01:00 UTC [daq     ] [Thread-6 (] [INFO    ] RAM Available: 1.7 GB, Used: 231.6 MB, Percent: 15.90%
2023-10-08 03:31:00 UTC [daq     ] [Thread-6 (] [INFO    ] RAM Available: 1.7 GB, Used: 230.7 MB, Percent: 15.80%

==> daq_2023-10-08-04-00-16.log <==
2023-10-14 23:01:00 UTC [daq     ] [Thread-6 (] [INFO    ] RAM Available: 1.7 GB, Used: 228.1 MB, Percent: 15.70%
2023-10-14 23:31:00 UTC [daq     ] [Thread-6 (] [INFO    ] RAM Available: 1.7 GB, Used: 230.2 MB, Percent: 15.80%
2023-10-15 00:01:00 UTC [daq     ] [Thread-6 (] [INFO    ] RAM Available: 1.7 GB, Used: 228.6 MB, Percent: 15.70%
2023-10-15 00:31:00 UTC [daq     ] [Thread-6 (] [INFO    ] RAM Available: 1.7 GB, Used: 229.4 MB, Percent: 15.80%
2023-10-15 01:01:00 UTC [daq     ] [Thread-6 (] [INFO    ] RAM Available: 1.7 GB, Used: 228.4 MB, Percent: 15.70%
2023-10-15 01:31:00 UTC [daq     ] [Thread-6 (] [INFO    ] RAM Available: 1.7 GB, Used: 229.9 MB, Percent: 15.80%
2023-10-15 02:01:00 UTC [daq     ] [Thread-6 (] [INFO    ] RAM Available: 1.7 GB, Used: 229.6 MB, Percent: 15.80%
2023-10-15 02:31:00 UTC [daq     ] [Thread-6 (] [INFO    ] RAM Available: 1.7 GB, Used: 229.8 MB, Percent: 15.80%
2023-10-15 03:01:00 UTC [daq     ] [Thread-6 (] [INFO    ] RAM Available: 1.7 GB, Used: 229.6 MB, Percent: 15.80%
2023-10-15 03:31:00 UTC [daq     ] [Thread-6 (] [INFO    ] RAM Available: 1.7 GB, Used: 231.4 MB, Percent: 15.90%

==> daq_2023-10-22-04-00-16.log <==
2023-10-28 23:01:00 UTC [daq     ] [Thread-6 (] [INFO    ] RAM Available: 1.7 GB, Used: 232.0 MB, Percent: 15.90%
2023-10-28 23:31:00 UTC [daq     ] [Thread-6 (] [INFO    ] RAM Available: 1.7 GB, Used: 230.3 MB, Percent: 15.80%
2023-10-29 00:01:00 UTC [daq     ] [Thread-6 (] [INFO    ] RAM Available: 1.7 GB, Used: 233.0 MB, Percent: 16.00%
2023-10-29 00:31:00 UTC [daq     ] [Thread-6 (] [INFO    ] RAM Available: 1.7 GB, Used: 231.9 MB, Percent: 15.90%
2023-10-29 01:01:00 UTC [daq     ] [Thread-6 (] [INFO    ] RAM Available: 1.7 GB, Used: 231.6 MB, Percent: 15.90%
2023-10-29 01:31:00 UTC [daq     ] [Thread-6 (] [INFO    ] RAM Available: 1.7 GB, Used: 233.3 MB, Percent: 16.00%
2023-10-29 02:01:00 UTC [daq     ] [Thread-6 (] [INFO    ] RAM Available: 1.7 GB, Used: 233.1 MB, Percent: 16.00%
2023-10-29 02:31:00 UTC [daq     ] [Thread-6 (] [INFO    ] RAM Available: 1.7 GB, Used: 233.6 MB, Percent: 16.00%
2023-10-29 03:01:00 UTC [daq     ] [Thread-6 (] [INFO    ] RAM Available: 1.7 GB, Used: 233.6 MB, Percent: 16.00%
2023-10-29 03:31:00 UTC [daq     ] [Thread-6 (] [INFO    ] RAM Available: 1.7 GB, Used: 234.1 MB, Percent: 16.00%

==> daq_2023-10-29-04-00-16.log <==
2023-11-04 17:31:00 UTC [daq     ] [Thread-6 (] [INFO    ] RAM Available: 1.7 GB, Used: 228.1 MB, Percent: 15.70%
2023-11-04 18:01:00 UTC [daq     ] [Thread-6 (] [INFO    ] RAM Available: 1.7 GB, Used: 228.1 MB, Percent: 15.70%
2023-11-04 18:31:00 UTC [daq     ] [Thread-6 (] [INFO    ] RAM Available: 1.7 GB, Used: 228.4 MB, Percent: 15.70%
2023-11-04 19:01:00 UTC [daq     ] [Thread-6 (] [INFO    ] RAM Available: 1.7 GB, Used: 228.4 MB, Percent: 15.70%
2023-11-04 19:31:00 UTC [daq     ] [Thread-6 (] [INFO    ] RAM Available: 1.7 GB, Used: 230.9 MB, Percent: 15.80%
2023-11-04 20:01:00 UTC [daq     ] [Thread-6 (] [INFO    ] RAM Available: 1.7 GB, Used: 229.4 MB, Percent: 15.80%
2023-11-04 20:31:00 UTC [daq     ] [Thread-6 (] [INFO    ] RAM Available: 1.7 GB, Used: 228.8 MB, Percent: 15.70%
2023-11-04 21:01:00 UTC [daq     ] [Thread-6 (] [INFO    ] RAM Available: 1.7 GB, Used: 230.3 MB, Percent: 15.80%
2023-11-04 21:31:00 UTC [daq     ] [Thread-6 (] [INFO    ] RAM Available: 1.7 GB, Used: 229.0 MB, Percent: 15.70%
2023-11-04 22:01:00 UTC [daq     ] [Thread-6 (] [INFO    ] RAM Available: 1.7 GB, Used: 231.1 MB, Percent: 15.90%

==> daq_2023-11-05-04-00-16.log <==
2023-11-12 00:01:00 UTC [daq     ] [Thread-6 (] [INFO    ] RAM Available: 1.7 GB, Used: 232.7 MB, Percent: 15.90%
2023-11-12 00:31:00 UTC [daq     ] [Thread-6 (] [INFO    ] RAM Available: 1.7 GB, Used: 232.2 MB, Percent: 15.90%
2023-11-12 01:01:00 UTC [daq     ] [Thread-6 (] [INFO    ] RAM Available: 1.7 GB, Used: 233.7 MB, Percent: 16.00%
2023-11-12 01:31:00 UTC [daq     ] [Thread-6 (] [INFO    ] RAM Available: 1.7 GB, Used: 233.8 MB, Percent: 16.00%
2023-11-12 02:01:00 UTC [daq     ] [Thread-6 (] [INFO    ] RAM Available: 1.7 GB, Used: 232.7 MB, Percent: 15.90%
2023-11-12 02:31:00 UTC [daq     ] [Thread-6 (] [INFO    ] RAM Available: 1.7 GB, Used: 233.9 MB, Percent: 16.00%
2023-11-12 03:01:00 UTC [daq     ] [Thread-6 (] [INFO    ] RAM Available: 1.7 GB, Used: 232.9 MB, Percent: 15.90%
2023-11-12 03:31:00 UTC [daq     ] [Thread-6 (] [INFO    ] RAM Available: 1.7 GB, Used: 234.9 MB, Percent: 16.00%
2023-11-12 04:01:00 UTC [daq     ] [Thread-6 (] [INFO    ] RAM Available: 1.7 GB, Used: 233.0 MB, Percent: 15.90%
2023-11-12 04:31:00 UTC [daq     ] [Thread-6 (] [INFO    ] RAM Available: 1.7 GB, Used: 235.1 MB, Percent: 16.00%
```
<!-- markdownlint-enable MD013 -->

## NOT Pre-allocated Results
`daq_2023-11-12-19-05-30.log` to `daq_2023-12-17-05-00-17.log`
have no pre-allocation, and more memory usage.
This concludes the test, restoring pre-allocation code.

<!-- markdownlint-disable MD013 -->
```bash
==> daq_2023-11-14-04-49-21.log <==
2023-11-19 00:01:00 UTC [daq     ] [Thread-6 (] [INFO    ] RAM Available: 1.6 GB, Used: 291.6 MB, Percent: 19.10%
2023-11-19 00:31:00 UTC [daq     ] [Thread-6 (] [INFO    ] RAM Available: 1.6 GB, Used: 291.0 MB, Percent: 19.00%
2023-11-19 01:01:00 UTC [daq     ] [Thread-6 (] [INFO    ] RAM Available: 1.6 GB, Used: 292.0 MB, Percent: 19.10%
2023-11-19 01:31:00 UTC [daq     ] [Thread-6 (] [INFO    ] RAM Available: 1.6 GB, Used: 292.4 MB, Percent: 19.10%
2023-11-19 02:01:00 UTC [daq     ] [Thread-6 (] [INFO    ] RAM Available: 1.6 GB, Used: 292.4 MB, Percent: 19.10%
2023-11-19 02:31:00 UTC [daq     ] [Thread-6 (] [INFO    ] RAM Available: 1.6 GB, Used: 293.1 MB, Percent: 19.10%
2023-11-19 03:01:00 UTC [daq     ] [Thread-6 (] [INFO    ] RAM Available: 1.6 GB, Used: 294.0 MB, Percent: 19.20%
2023-11-19 03:31:00 UTC [daq     ] [Thread-6 (] [INFO    ] RAM Available: 1.6 GB, Used: 292.7 MB, Percent: 19.10%
2023-11-19 04:01:00 UTC [daq     ] [Thread-6 (] [INFO    ] RAM Available: 1.6 GB, Used: 293.1 MB, Percent: 19.20%
2023-11-19 04:31:00 UTC [daq     ] [Thread-6 (] [INFO    ] RAM Available: 1.6 GB, Used: 293.9 MB, Percent: 19.20%

==> daq_2023-11-19-05-00-16.log <==
2023-11-24 12:01:00 UTC [daq     ] [Thread-6 (] [INFO    ] RAM Available: 1.6 GB, Used: 268.4 MB, Percent: 17.70%
2023-11-24 12:31:00 UTC [daq     ] [Thread-6 (] [INFO    ] RAM Available: 1.6 GB, Used: 270.2 MB, Percent: 17.80%
2023-11-24 13:01:00 UTC [daq     ] [Thread-6 (] [INFO    ] RAM Available: 1.6 GB, Used: 269.5 MB, Percent: 17.80%
2023-11-24 13:31:00 UTC [daq     ] [Thread-6 (] [INFO    ] RAM Available: 1.6 GB, Used: 269.4 MB, Percent: 17.80%
2023-11-24 14:01:00 UTC [daq     ] [Thread-6 (] [INFO    ] RAM Available: 1.6 GB, Used: 270.6 MB, Percent: 17.90%
2023-11-24 14:31:00 UTC [daq     ] [Thread-6 (] [INFO    ] RAM Available: 1.6 GB, Used: 268.5 MB, Percent: 17.70%
2023-11-24 15:01:00 UTC [daq     ] [Thread-6 (] [INFO    ] RAM Available: 1.6 GB, Used: 269.9 MB, Percent: 17.80%
2023-11-24 15:31:00 UTC [daq     ] [Thread-6 (] [INFO    ] RAM Available: 1.6 GB, Used: 271.7 MB, Percent: 17.90%
2023-11-24 16:01:00 UTC [daq     ] [Thread-6 (] [INFO    ] RAM Available: 1.6 GB, Used: 271.4 MB, Percent: 17.90%
2023-11-24 16:31:00 UTC [daq     ] [Thread-6 (] [INFO    ] RAM Available: 1.6 GB, Used: 270.0 MB, Percent: 17.80%

==> daq_2023-11-26-05-05-39.log <==
2023-12-03 00:01:00 UTC [daq     ] [Thread-6 (] [INFO    ] RAM Available: 1.6 GB, Used: 287.4 MB, Percent: 18.80%
2023-12-03 00:31:00 UTC [daq     ] [Thread-6 (] [INFO    ] RAM Available: 1.6 GB, Used: 287.8 MB, Percent: 18.80%
2023-12-03 01:01:00 UTC [daq     ] [Thread-6 (] [INFO    ] RAM Available: 1.6 GB, Used: 287.0 MB, Percent: 18.70%
2023-12-03 01:31:00 UTC [daq     ] [Thread-6 (] [INFO    ] RAM Available: 1.6 GB, Used: 288.1 MB, Percent: 18.80%
2023-12-03 02:01:00 UTC [daq     ] [Thread-6 (] [INFO    ] RAM Available: 1.6 GB, Used: 287.2 MB, Percent: 18.80%
2023-12-03 02:31:00 UTC [daq     ] [Thread-6 (] [INFO    ] RAM Available: 1.6 GB, Used: 287.2 MB, Percent: 18.80%
2023-12-03 03:01:00 UTC [daq     ] [Thread-6 (] [INFO    ] RAM Available: 1.6 GB, Used: 287.9 MB, Percent: 18.80%
2023-12-03 03:31:00 UTC [daq     ] [Thread-6 (] [INFO    ] RAM Available: 1.6 GB, Used: 288.0 MB, Percent: 18.80%
2023-12-03 04:01:00 UTC [daq     ] [Thread-6 (] [INFO    ] RAM Available: 1.6 GB, Used: 290.3 MB, Percent: 18.90%
2023-12-03 04:31:00 UTC [daq     ] [Thread-6 (] [INFO    ] RAM Available: 1.6 GB, Used: 289.5 MB, Percent: 18.90%

==> daq_2023-12-03-05-00-17.log <==
2023-12-10 01:31:00 UTC [daq     ] [Thread-6 (] [INFO    ] RAM Available: 1.6 GB, Used: 288.0 MB, Percent: 18.70%
2023-12-10 02:01:00 UTC [daq     ] [Thread-6 (] [INFO    ] RAM Available: 1.6 GB, Used: 288.1 MB, Percent: 18.70%
2023-12-10 02:31:00 UTC [daq     ] [Thread-6 (] [INFO    ] RAM Available: 1.6 GB, Used: 288.1 MB, Percent: 18.70%
2023-12-10 03:01:00 UTC [daq     ] [Thread-6 (] [INFO    ] RAM Available: 1.6 GB, Used: 287.8 MB, Percent: 18.70%
2023-12-10 03:31:00 UTC [daq     ] [Thread-6 (] [INFO    ] RAM Available: 1.6 GB, Used: 287.3 MB, Percent: 18.70%
2023-12-10 04:01:00 UTC [daq     ] [Thread-6 (] [INFO    ] RAM Available: 1.6 GB, Used: 288.8 MB, Percent: 18.70%
2023-12-10 04:31:00 UTC [daq     ] [Thread-6 (] [INFO    ] RAM Available: 1.6 GB, Used: 288.8 MB, Percent: 18.70%

==> daq_2023-12-10-05-00-17.log <==
2023-12-17 00:01:00 UTC [daq     ] [Thread-6 (] [INFO    ] RAM Available: 1.6 GB, Used: 287.2 MB, Percent: 18.80%
2023-12-17 00:31:00 UTC [daq     ] [Thread-6 (] [INFO    ] RAM Available: 1.6 GB, Used: 285.4 MB, Percent: 18.70%
2023-12-17 01:01:00 UTC [daq     ] [Thread-6 (] [INFO    ] RAM Available: 1.6 GB, Used: 286.4 MB, Percent: 18.80%
2023-12-17 01:31:00 UTC [daq     ] [Thread-6 (] [INFO    ] RAM Available: 1.6 GB, Used: 286.3 MB, Percent: 18.80%
2023-12-17 02:01:00 UTC [daq     ] [Thread-6 (] [INFO    ] RAM Available: 1.6 GB, Used: 285.2 MB, Percent: 18.70%
2023-12-17 02:31:00 UTC [daq     ] [Thread-6 (] [INFO    ] RAM Available: 1.6 GB, Used: 286.8 MB, Percent: 18.80%
2023-12-17 03:01:00 UTC [daq     ] [Thread-6 (] [INFO    ] RAM Available: 1.6 GB, Used: 287.3 MB, Percent: 18.80%
2023-12-17 03:31:00 UTC [daq     ] [Thread-6 (] [INFO    ] RAM Available: 1.6 GB, Used: 287.7 MB, Percent: 18.80%
2023-12-17 04:01:00 UTC [daq     ] [Thread-6 (] [INFO    ] RAM Available: 1.6 GB, Used: 288.0 MB, Percent: 18.80%
2023-12-17 04:31:00 UTC [daq     ] [Thread-6 (] [INFO    ] RAM Available: 1.6 GB, Used: 287.5 MB, Percent: 18.80%
```
<!-- markdownlint-enable MD013 -->

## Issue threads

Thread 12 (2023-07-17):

Non-fatal exception in `daq.py` related to serving web page

mepland, 2023-07-17:
This non-fatal exception comes up intermittently in `daq.py`. It seems related to the live web page served by flask, but is not being caught by any of the current `try except` blocks.
```bash
Traceback (most recent call last):
  File "/usr/lib/python3.9/threading.py", line 954, in _bootstrap_inner
    self.run()
  File "/usr/lib/python3.9/threading.py", line 892, in run
    self._target(*self._args, **self._kwargs)
  File "/home/mepland/.cache/pypoetry/virtualenvs/chance-of-showers-7HAEcyu8-py3.9/lib/python3.9/site-packages/simple_websocket/ws.py", line 169, in _thread
    self.connected = self._handle_events()
  File "/home/mepland/.cache/pypoetry/virtualenvs/chance-of-showers-7HAEcyu8-py3.9/lib/python3.9/site-packages/simple_websocket/ws.py", line 249, in _handle_events
    self.sock.send(out_data)
```

mepland, 2023-12-18:
This bug has not reoccurred in the last ~ 6 months. Closing this issue.

Closed 2023-12-18.

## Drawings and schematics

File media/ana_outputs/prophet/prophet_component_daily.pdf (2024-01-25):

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

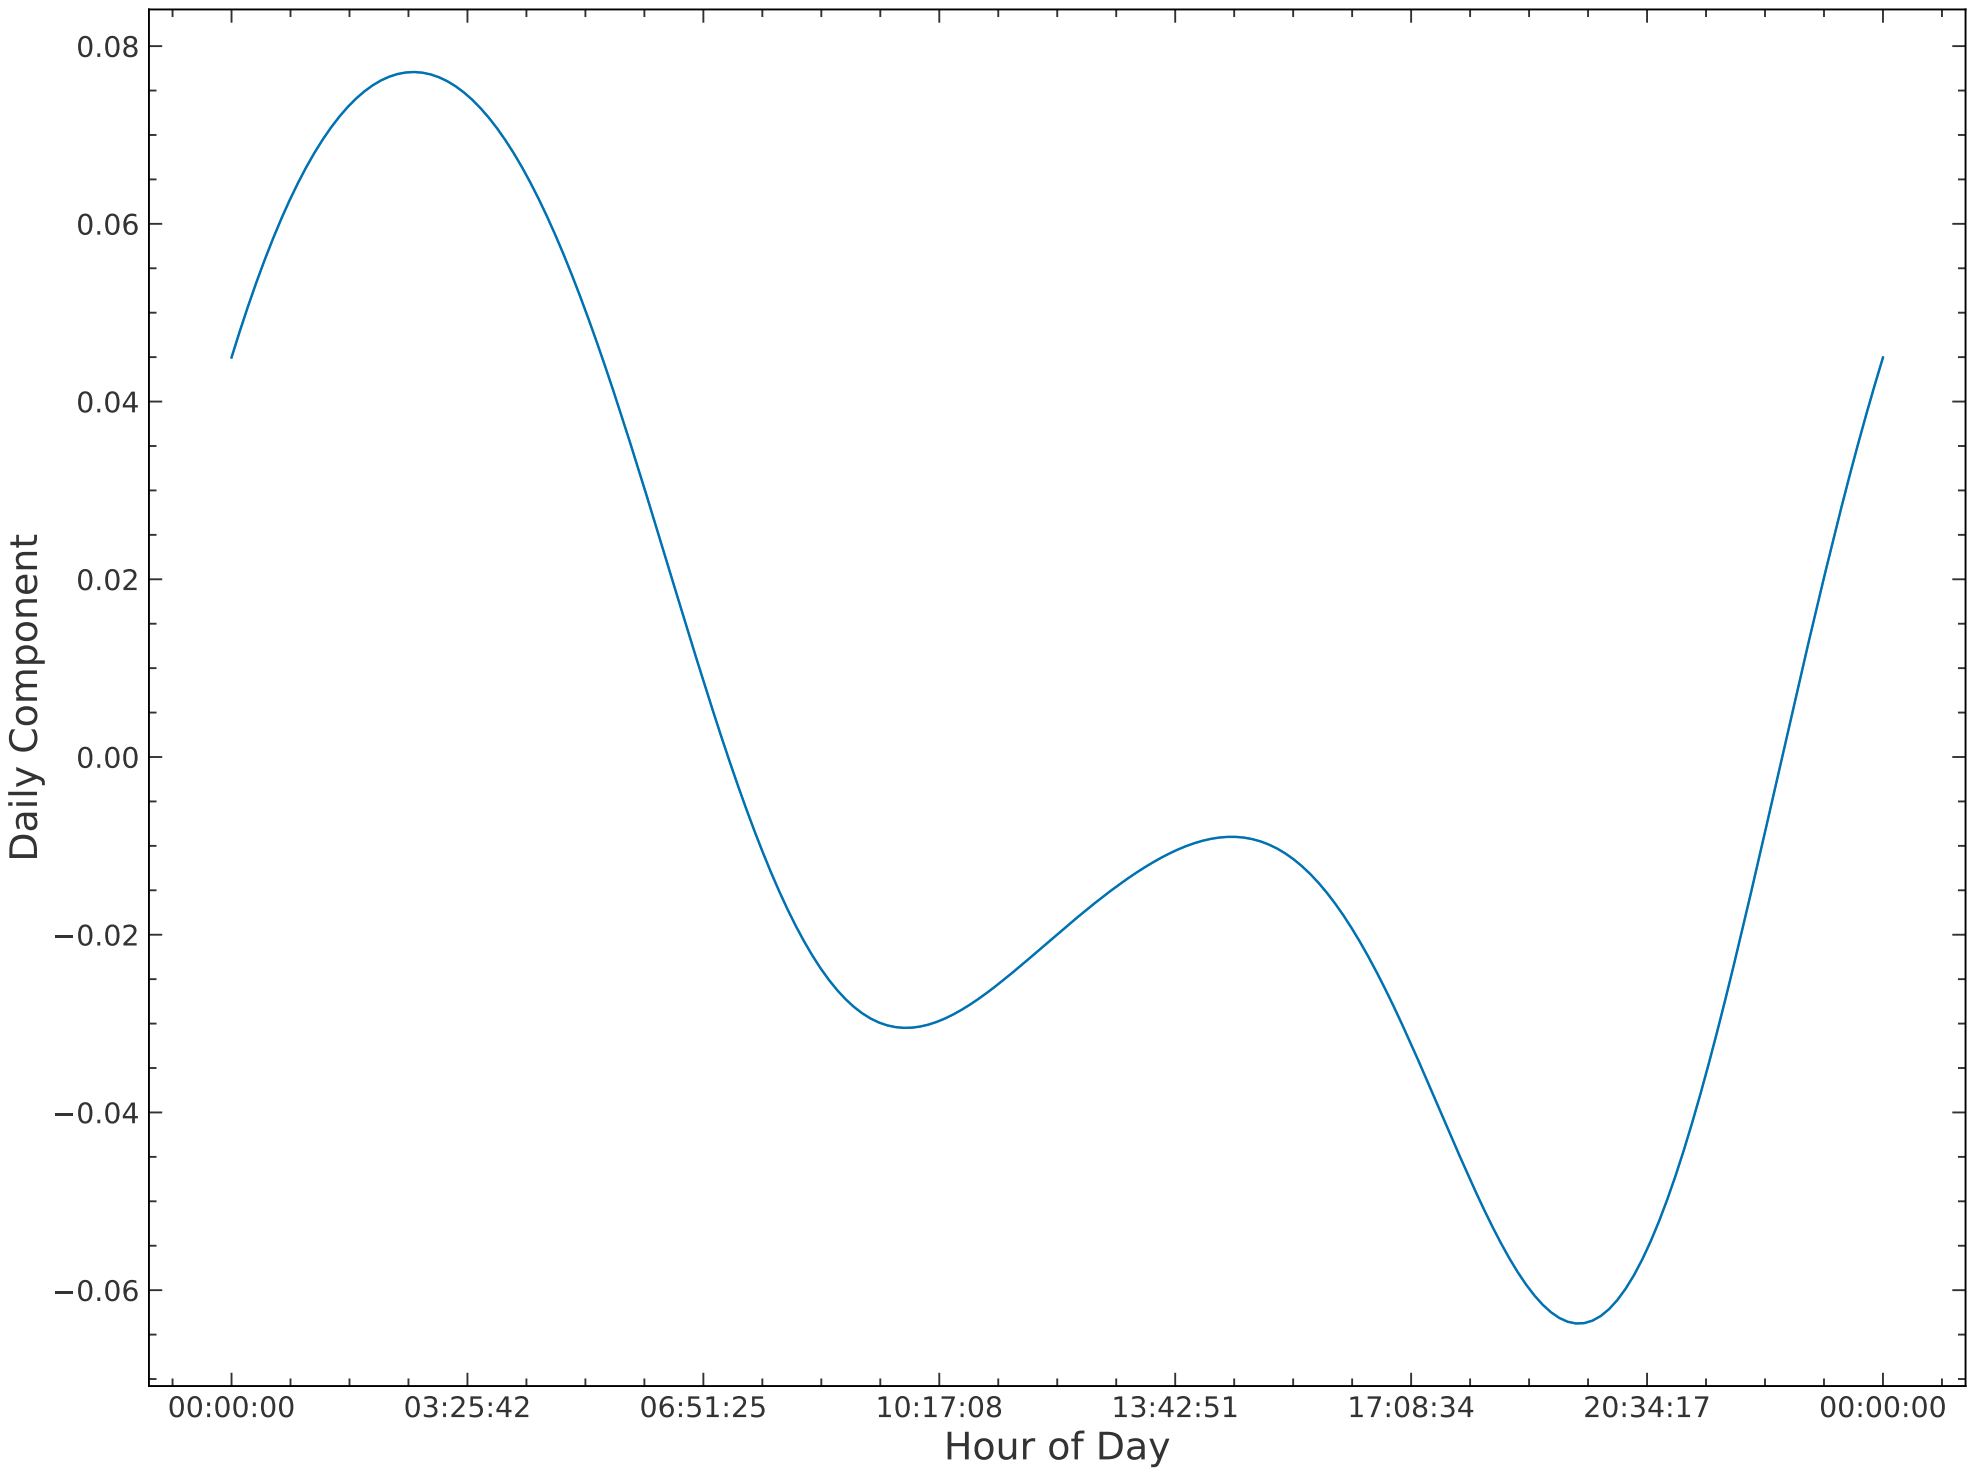
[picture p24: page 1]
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

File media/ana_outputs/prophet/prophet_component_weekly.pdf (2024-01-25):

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

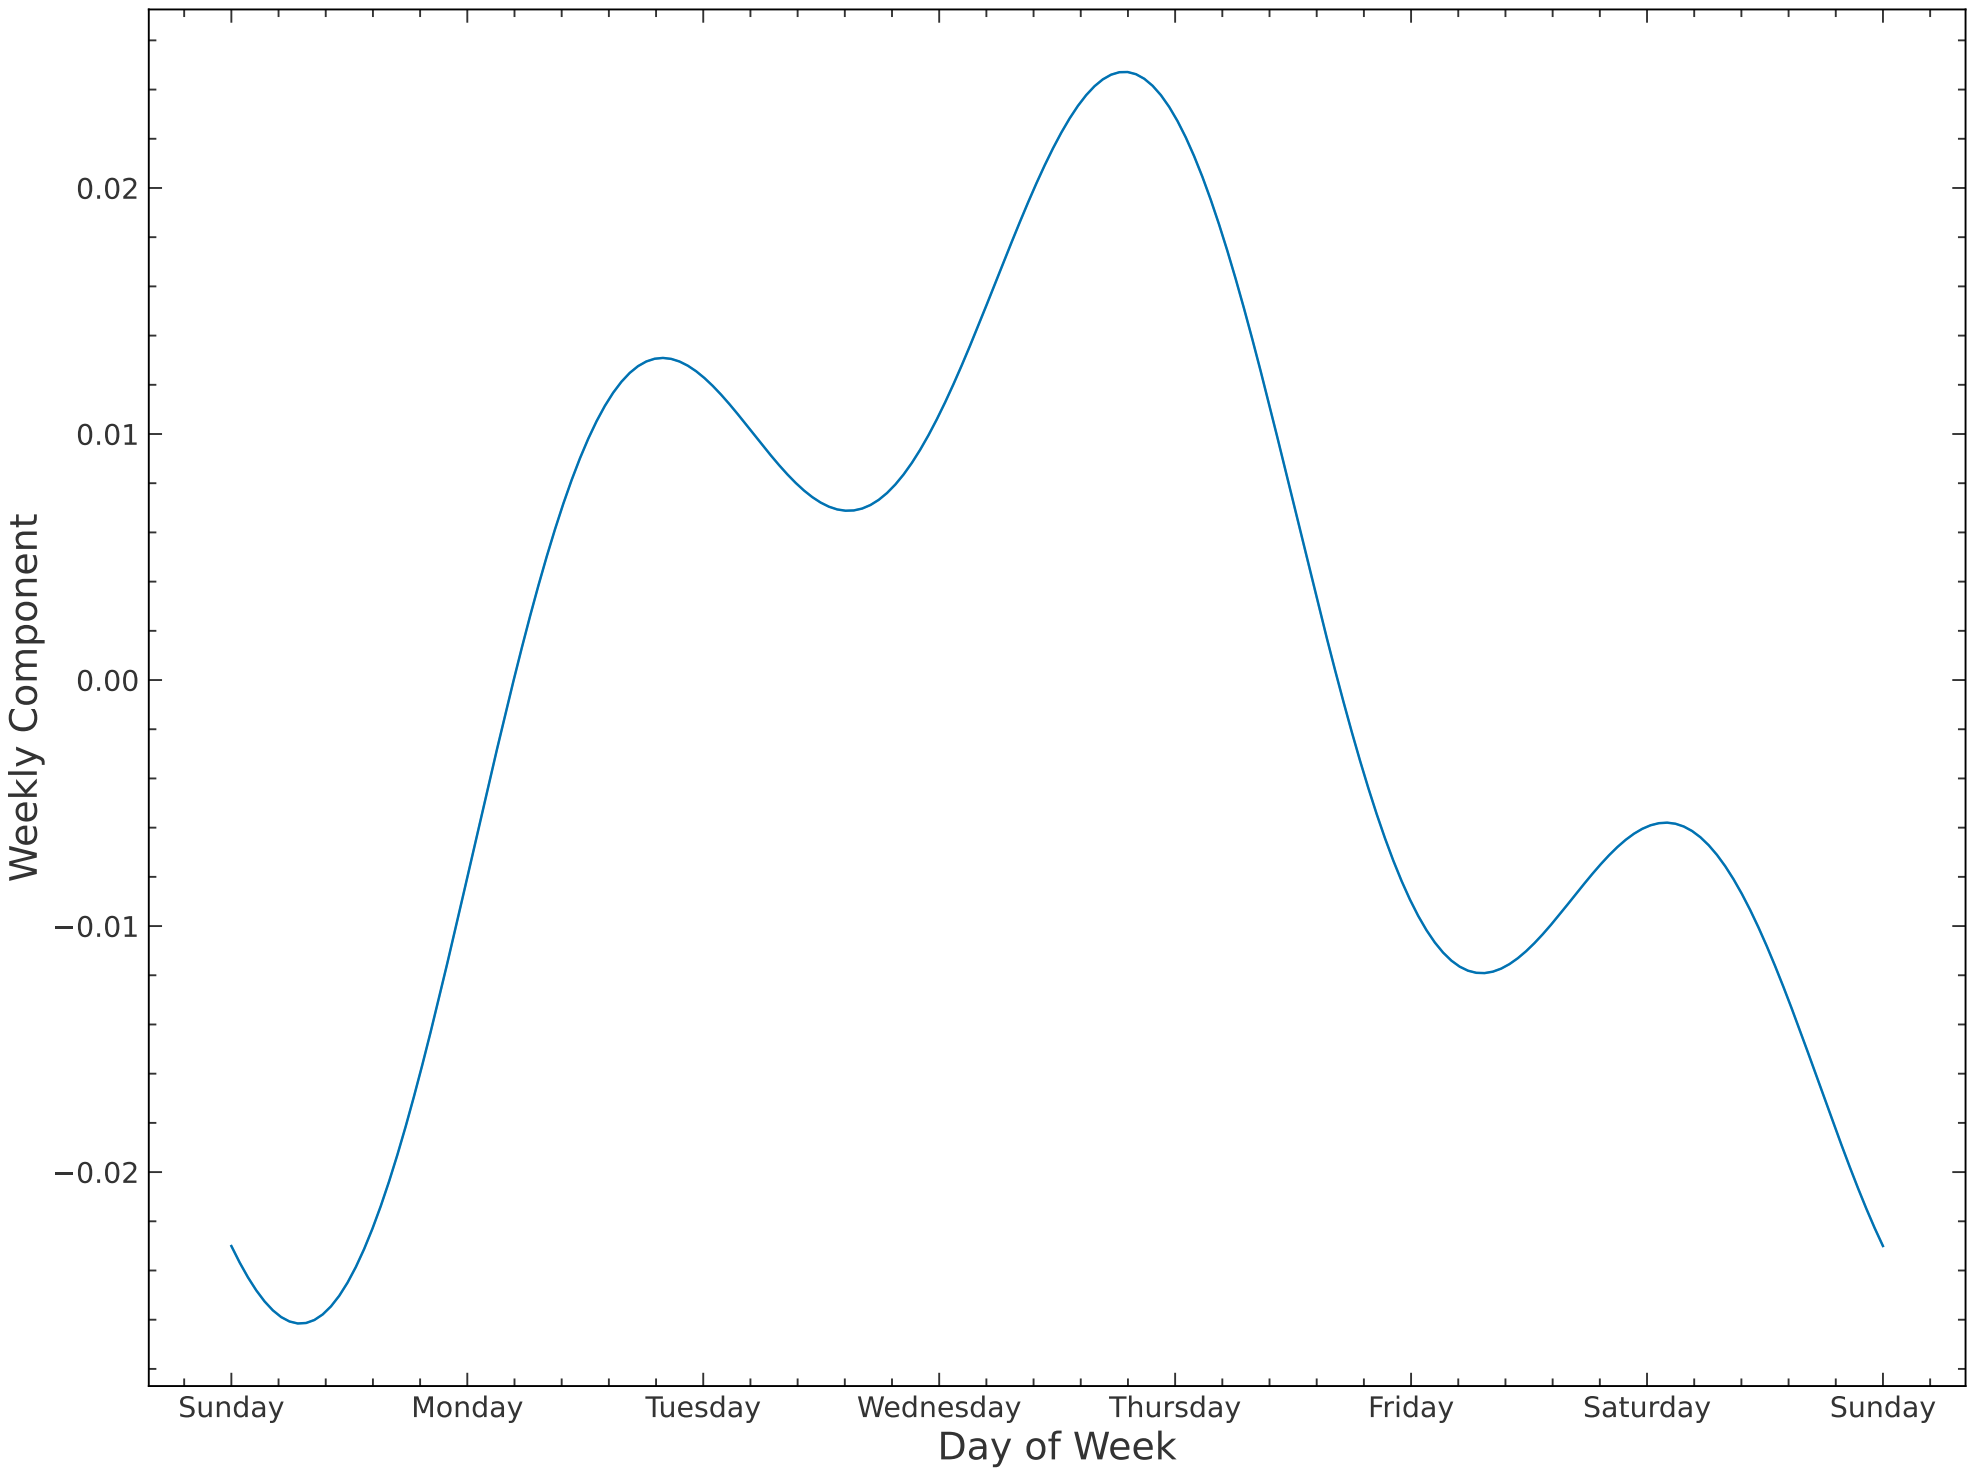
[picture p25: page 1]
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

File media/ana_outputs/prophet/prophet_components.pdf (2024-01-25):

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

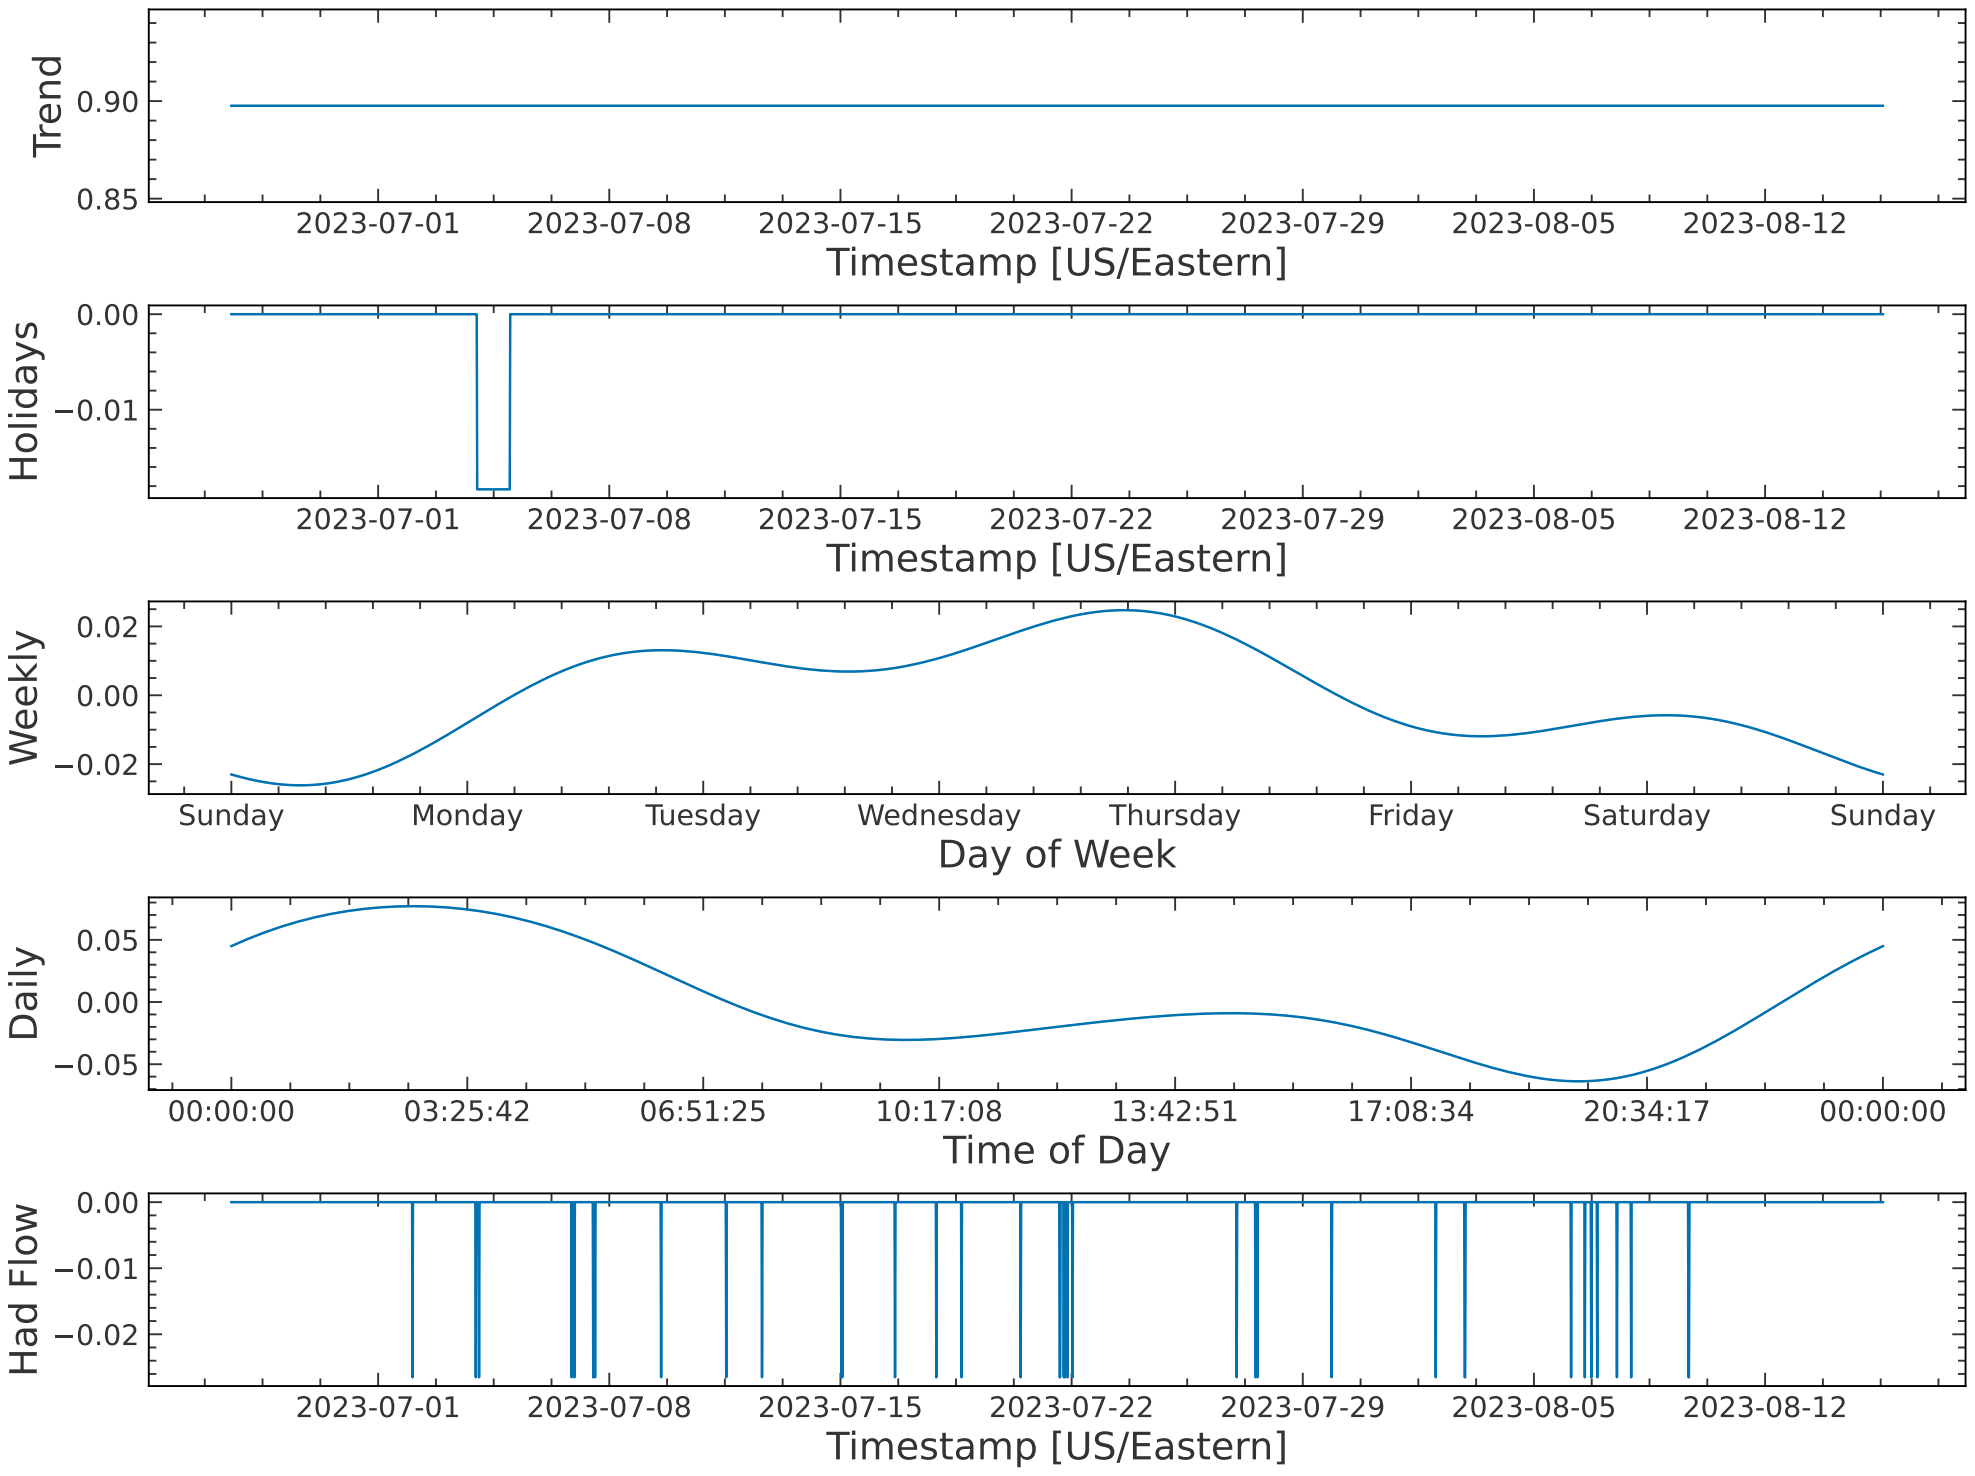
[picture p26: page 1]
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

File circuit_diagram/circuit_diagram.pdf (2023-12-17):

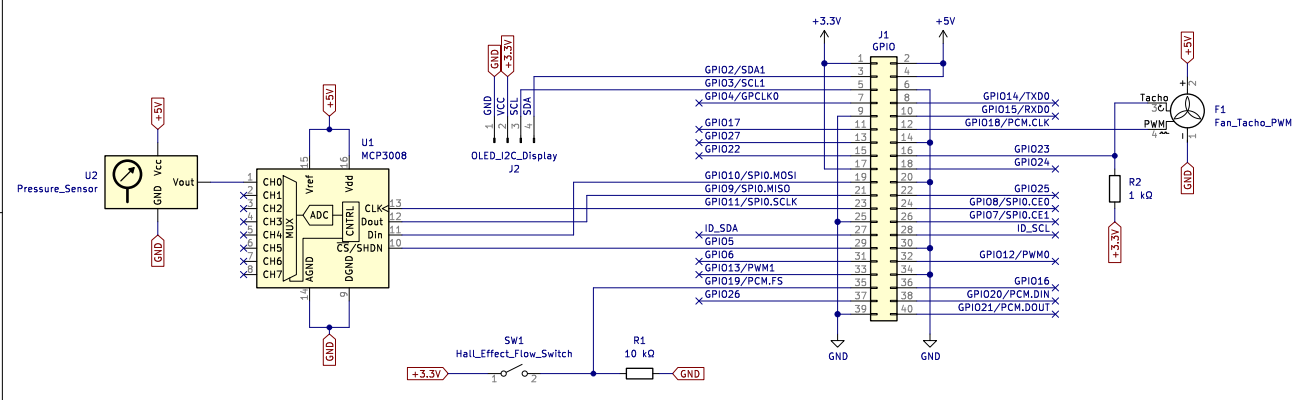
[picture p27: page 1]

Id: 1/1 Title: Chance of Showers

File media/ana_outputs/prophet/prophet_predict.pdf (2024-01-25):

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

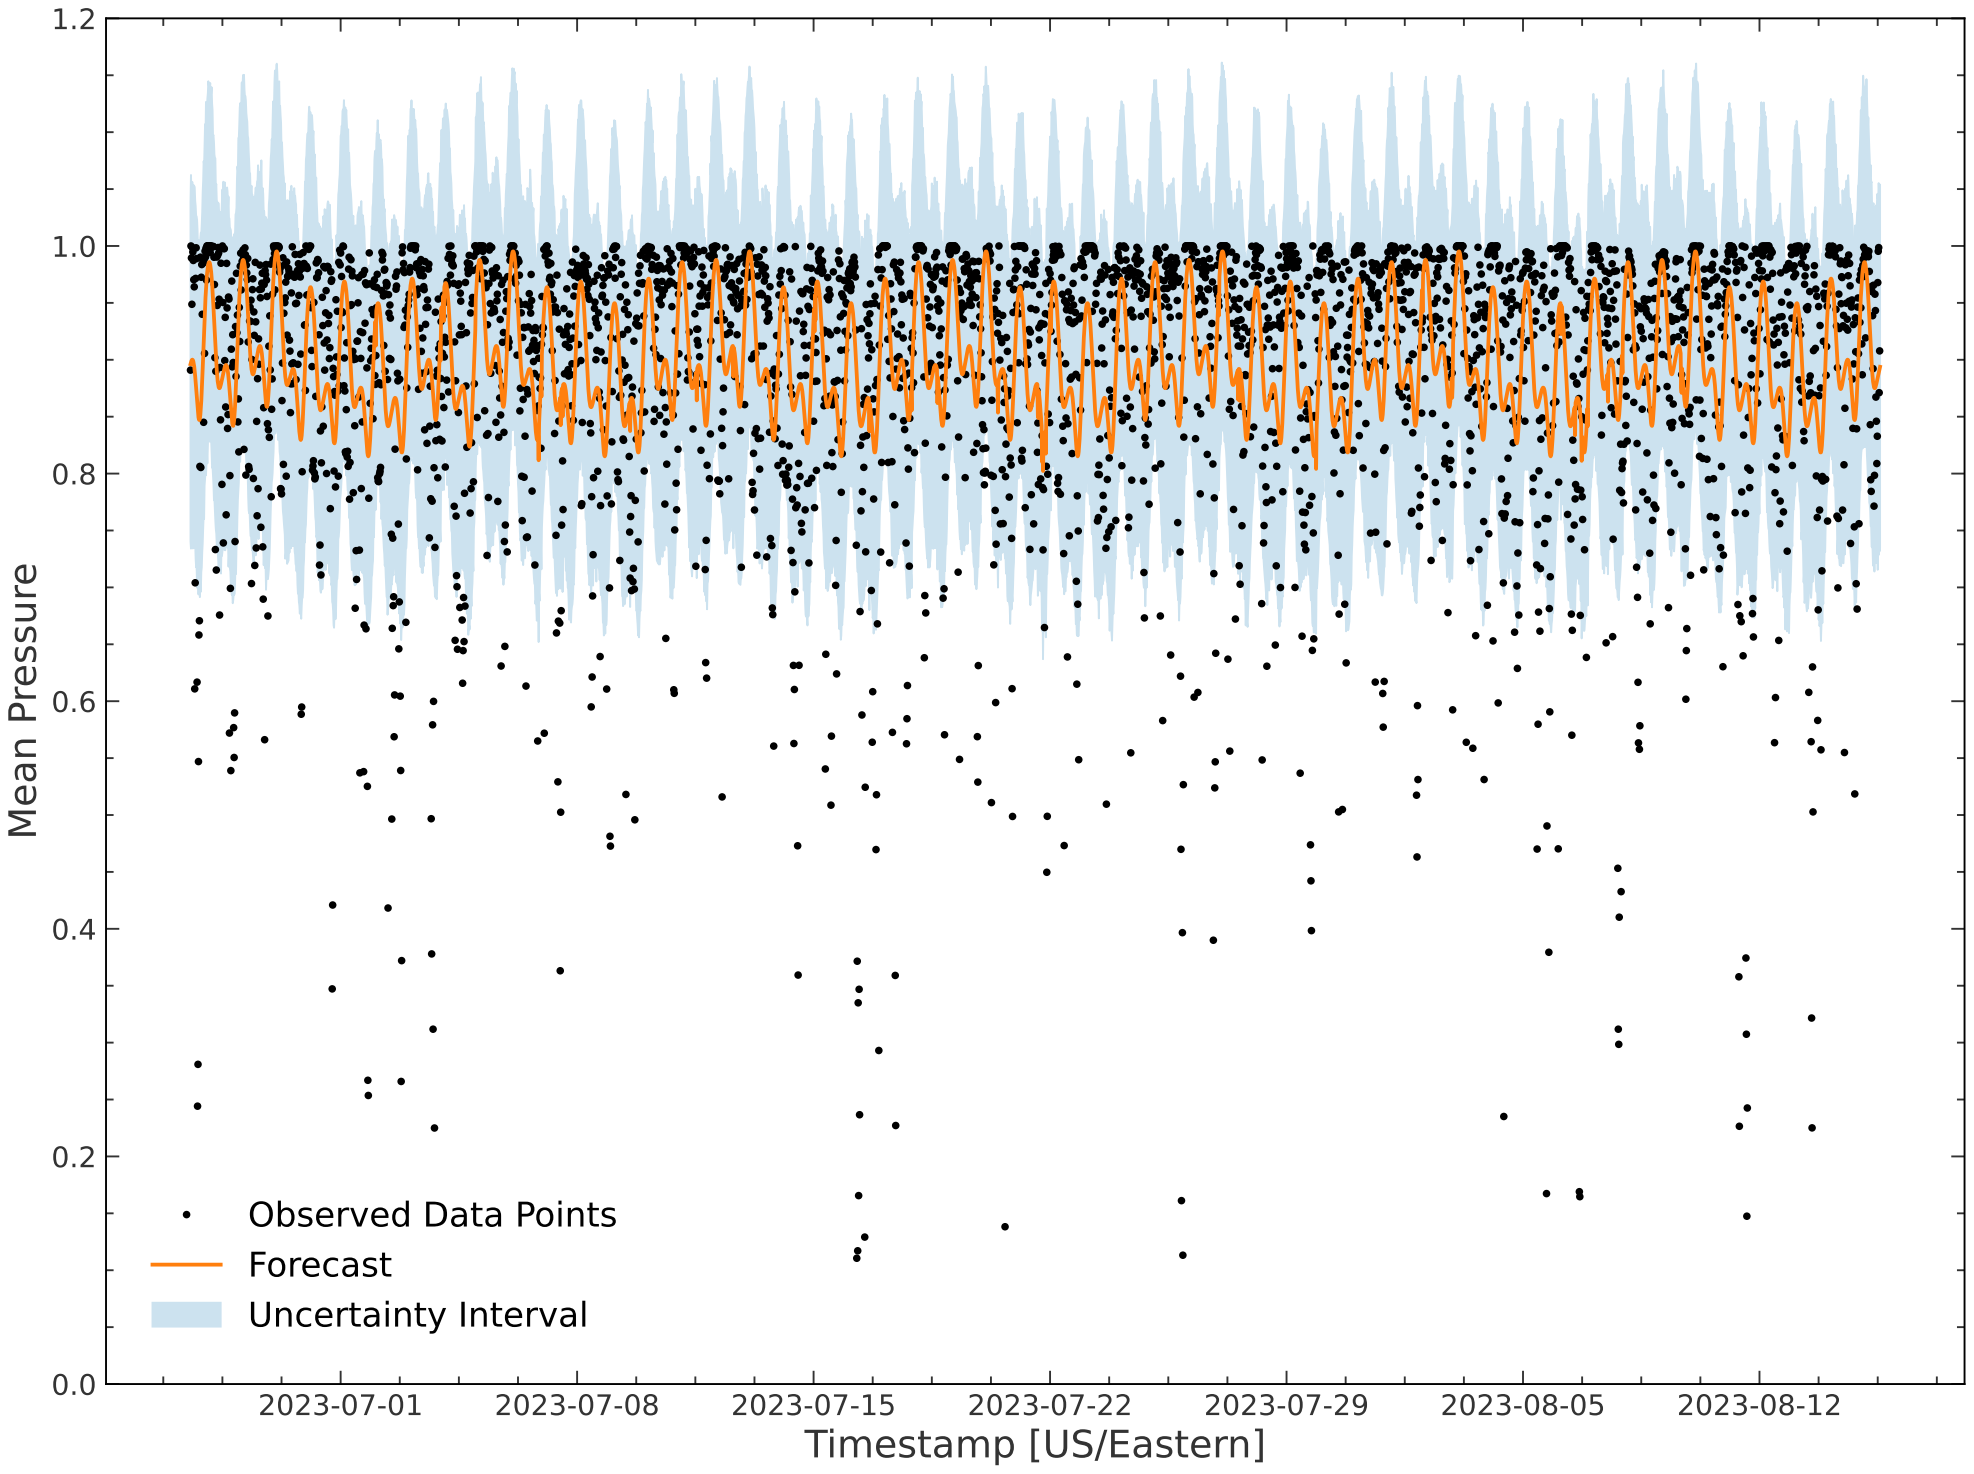
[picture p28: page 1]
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

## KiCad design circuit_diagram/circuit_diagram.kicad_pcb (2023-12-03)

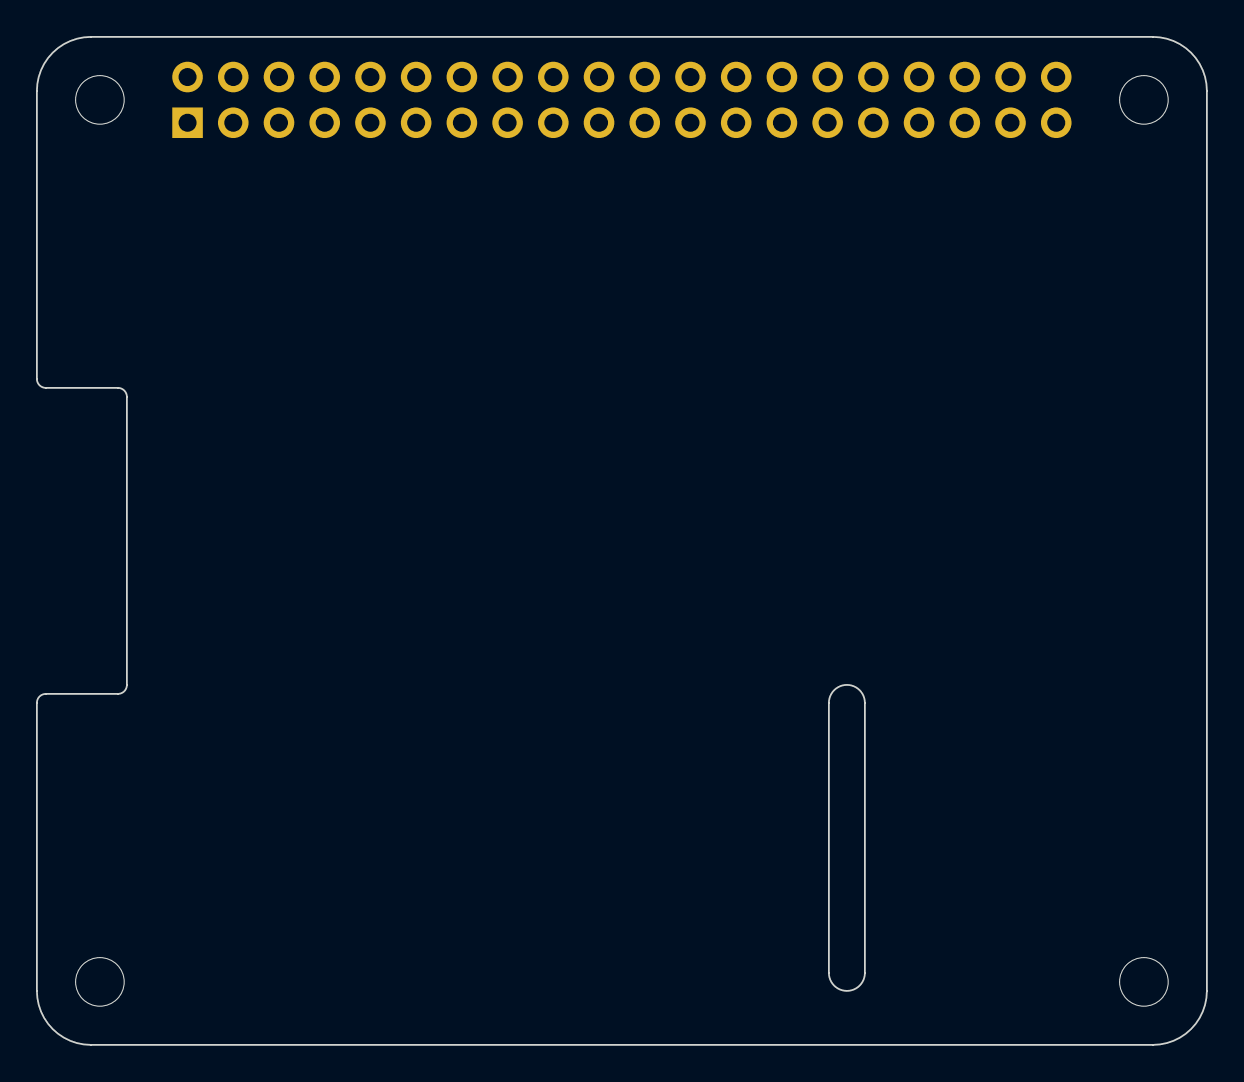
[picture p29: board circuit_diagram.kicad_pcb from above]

Board: 2 copper layers, 65.0 x 56.0 mm, 5 parts (1 on the bottom side), 3 nets, no tracks yet.

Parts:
J1: GPIO; PinSocket_2x20_P2.54mm_Vertical
MH1, MH2, MH3, MH4: MountingHole_2.7mm_M2.5

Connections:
+3V3: J1.1, J1.17
+5V: J1.2, J1.4
GND: J1.6, J1.9, J1.14, J1.20, J1.25, J1.30, J1.34, J1.39

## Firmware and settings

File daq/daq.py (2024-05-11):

"""Run DAQ script."""

from __future__ import annotations

import datetime
import logging
import pathlib
import signal
import socket
import sys
import threading
import time
import traceback
import zoneinfo
from csv import writer
from typing import TYPE_CHECKING, Final

import humanize
import hydra
import numpy as np
import pause
import psutil
from omegaconf import DictConfig  # noqa: TC002

__all__: list[str] = []


if TYPE_CHECKING:
    from types import FrameType

# pylint: disable=import-outside-toplevel

# Global variables
# pylint: disable=invalid-name
thread_daq_loop = None
running_daq_loop = True
had_flow = 0
new_connection = False
# pylint: enable=invalid-name


@hydra.main(version_base=None, config_path="..", config_name="config")
def daq(  # noqa: C901 # pylint: disable=too-many-statements, too-many-locals
    cfg: DictConfig,
) -> None:
    """Run the DAQ script.

    Args:
        cfg (DictConfig): Hydra configuration.

    Raises:
        ValueError: Bad configuration.
    """
    global thread_daq_loop
    global running_daq_loop
    global had_flow
    global new_connection
    # Setup variables
    # pylint: disable=invalid-name
    LOG_TO_FILE: Final = cfg["daq"]["log_to_file"]
    DISPLAY_TERMINAL: Final = cfg["daq"]["display_terminal"]
    DISPLAY_TERMINAL_OVERWRITE: Final = cfg["daq"]["display_terminal_overwrite"]
    DISPLAY_OLED: Final = cfg["daq"]["display_oled"]
    DISPLAY_WEB: Final = cfg["daq"]["display_web"]
    DISPLAY_WEB_LOGGING_TERMINAL: Final = cfg["daq"]["display_web_logging_terminal"]
    VERBOSITY: Final = cfg["daq"]["verbosity"]

    STARTING_TIME_MINUTES_MOD: Final = cfg["daq"]["starting_time_minutes_mod"]
    AVERAGING_PERIOD_SECONDS: Final = cfg["daq"]["averaging_period_seconds"]
    POLLING_PERIOD_SECONDS: Final = cfg["daq"]["polling_period_seconds"]

    DATE_FMT: Final = cfg["general"]["date_fmt"]
    TIME_FMT: Final = cfg["general"]["time_fmt"]
    DATETIME_FMT: Final = f"{DATE_FMT} {TIME_FMT}"
    FNAME_DATETIME_FMT: Final = cfg["general"]["fname_datetime_fmt"]
    LOCAL_TIMEZONE_STR: Final = cfg["general"]["local_timezone"]

    if LOCAL_TIMEZONE_STR not in zoneinfo.available_timezones():
        AVAILABLE_TIMEZONES: Final = "\n".join(list(zoneinfo.available_timezones()))
        raise ValueError(f"Unknown {LOCAL_TIMEZONE_STR = }, choose from:\n{AVAILABLE_TIMEZONES}")

    UTC_TIMEZONE: Final = zoneinfo.ZoneInfo("UTC")
    # Do not use get_local_timezone_from_cfg() due to the way utils.shared_functions is imported.
    LOCAL_TIMEZONE: Final = zoneinfo.ZoneInfo(LOCAL_TIMEZONE_STR)

    PACKAGE_PATH: Final = pathlib.Path(cfg["general"]["package_path"]).expanduser()

    RAW_DATA_RELATIVE_PATH: Final = cfg["daq"]["raw_data_relative_path"]
    LOGS_RELATIVE_PATH: Final = cfg["daq"]["logs_relative_path"]

    LOG_MEMORY_USAGE: Final = cfg["daq"]["log_memory_usage"]
    LOG_MEMORY_USAGE_MINUTES_MOD: Final = cfg["daq"]["log_memory_usage_minutes_mod"]

    N_LAST_POINTS_WEB: Final = cfg["daq"]["n_last_points_web"]

    OBSERVED_PRESSURE_MIN: Final = cfg["general"]["observed_pressure_min"]
    OBSERVED_PRESSURE_MAX: Final = cfg["general"]["observed_pressure_max"]

    # DAQ variables
    N_POLLING: Final = int(np.ceil(AVERAGING_PERIOD_SECONDS / POLLING_PERIOD_SECONDS))
    # pylint: enable=invalid-name

    # Defining these arrays here first saves memory
    polling_pressure_samples = np.empty(N_POLLING)
    polling_pressure_samples.fill(np.nan)
    polling_flow_samples = np.zeros(N_POLLING)  # noqa: F841 # pylint: disable=unused-variable

    # Lock script, avoid launching duplicates
    sys.path.append(str(pathlib.Path.cwd().parent))
    from utils.shared_functions import get_lock, get_SoC_temp, normalize_pressure_value

    get_lock("daq")

    # Setup paths
    RAW_DATA_FULL_PATH: Final = (  # pylint: disable=invalid-name
        PACKAGE_PATH / RAW_DATA_RELATIVE_PATH
    )
    LOGS_FULL_PATH: Final = PACKAGE_PATH / LOGS_RELATIVE_PATH  # pylint: disable=invalid-name
    RAW_DATA_FULL_PATH.mkdir(parents=True, exist_ok=True)
    LOGS_FULL_PATH.mkdir(parents=True, exist_ok=True)

    # Setup logging
    logger_daq = logging.getLogger("daq")
    logger_daq.setLevel(logging.INFO)
    if 0 < VERBOSITY:
        logger_daq.setLevel(logging.DEBUG)

    if LOG_TO_FILE:
        LOG_DATETIME: Final = datetime.datetime.now(  # pylint: disable=invalid-name
            UTC_TIMEZONE
        ).strftime(FNAME_DATETIME_FMT)

        FNAME_LOG: Final = f"daq_{LOG_DATETIME}.log"  # pylint: disable=invalid-name
        logging_fh = logging.FileHandler(LOGS_FULL_PATH / FNAME_LOG)
        logging_fh.setLevel(logging.INFO)
        if 0 < VERBOSITY:
            logging_fh.setLevel(logging.DEBUG)

        logging_formatter = logging.Formatter(
            "%(asctime)s [%(name)-8.8s] [%(threadName)-10.10s] [%(levelname)-8.8s] %(message)s",
            f"{DATETIME_FMT} UTC",
        )
        # https://docs.python.org/3/library/logging.html#logging.Formatter.formatTime
        # https://docs.python.org/3/library/time.html#time.gmtime
        logging_formatter.converter = time.gmtime  # GMT = UTC

        logging_fh.setFormatter(logging_formatter)

        logger_daq.addHandler(logging_fh)

    def my_print(
        line: str,
        *,
        logger_level: int | None = logging.INFO,
        use_print: bool = DISPLAY_TERMINAL,
        print_prefix: str = "",
        print_postfix: str = "",
        use_stdout_overwrite: bool = False,
    ) -> None:
        """Custom print function to print to screen and log files.

        We could just add a StreamHandler to logger,
        but as we also want to erase lines on stdout we define our own print function instead.

        Args:
            line (str): The line to be printed.
            logger_level (int | None): The level to use for logging, None to disable logging. (Default value = logging.INFO)
            use_print (bool): Flag for printing to stdout. (Default value = DISPLAY_TERMINAL)
            print_prefix (str): String to prepend to `line` before printing to stdout. (Default value = '')
            print_postfix (str): String to append to `line` before printing to stdout. (Default value = '')
            use_stdout_overwrite (bool): Flag for overwriting the previous line on stdout. (Default value = False)
        """
        if not LOG_TO_FILE or logger_level is None:
            pass
        elif logger_level == logging.CRITICAL:
            logger_daq.critical(line)
        elif logger_level == logging.ERROR:
            logger_daq.error(line)
        elif logger_level == logging.WARNING:
            logger_daq.warning(line)
        elif logger_level == logging.INFO:
            logger_daq.info(line)
        elif logger_level == logging.DEBUG:
            logger_daq.debug(line)
        else:
            logger_daq.critical(
                f"Unknown {logger_level = }, {type(logger_level) = } in my_print, logging as {logging.CRITICAL = }"
            )
            logger_daq.critical(line)

        if use_print:
            print(f"{print_prefix}{line}{print_postfix}")
        elif use_stdout_overwrite:
            # https://stackoverflow.com/a/39177802
            sys.stdout.write("\x1b[1A\x1b[2K" + line + "\r")
            sys.stdout.flush()

    # Helper variables and functions

    def normalize_pressure_value_safe(pressure_value: int) -> float:
        """Normalize raw ADC pressure_value.

        Args:
            pressure_value (int): The raw ADC pressure_value to be normalized.

        Returns:
            float: (pressure_value-observed_pressure_min)/(observed_pressure_max-observed_pressure_min),
                i.e. observed_pressure_min (observed_pressure_max) maps to 0 (1).
        """
        normalize_pressure_value_float = -1.0
        try:
            normalize_pressure_value_float = normalize_pressure_value(
                pressure_value, OBSERVED_PRESSURE_MIN, OBSERVED_PRESSURE_MAX
            )
        except Exception as error:
            # don't want to kill the DAQ just because of a display problem
            # Note normalize_pressure_value() is only used to populate the displays, not save the raw data
            my_print(
                f"Unexpected error in normalize_pressure_value():\n{error = }\n{type(error) = }\n{traceback.format_exc()}\nContinuing",
                logger_level=logging.DEBUG,
                use_print=False,
            )

        return normalize_pressure_value_float

    def get_SoC_temp_safe() -> float:  # pylint: disable=invalid-name
        """Get SoC's temperature.

        Returns:
            float: SoC temperature.
        """
        temp = -1.0
        try:
            temp = get_SoC_temp()
        except Exception as error:
            # don't want to kill the DAQ just because of a problem reading the SoC temp
            my_print(
                f"Unexpected error in get_SoC_temp():\n{error = }\n{type(error) = }\n{traceback.format_exc()}\nContinuing",
                logger_level=logging.DEBUG,
                use_print=False,
            )
            pass

        return temp

    def signal_handler(
        dummy_signal: int,  # noqa: U100 # pylint: disable=unused-argument
        dummy_frame: FrameType | None,  # noqa: U100 # pylint: disable=unused-argument
    ) -> None:
        """Catch ctrl+c and kill, and shut down gracefully.

        https://stackoverflow.com/a/38665760
        Use the running_daq_loop variable and a pause of 2 * polling_period_seconds seconds to end the daq_loop() thread gracefully

        Args:
            dummy_signal (int): signal number.
            dummy_frame (FrameType | None): Frame object.
        """
        global running_daq_loop
        my_print(
            f"DAQ loop will exit gracefully in {2 * POLLING_PERIOD_SECONDS} seconds",
            print_prefix="\n",
        )
        running_daq_loop = False
        time.sleep(2 * POLLING_PERIOD_SECONDS)
        my_print("DAQ exiting gracefully", print_prefix="\n")
        sys.exit(0)

    signal.signal(signal.SIGINT, signal_handler)

    # Setup connection to MCP3008 ADC
    # https://docs.circuitpython.org/projects/mcp3xxx/en/stable/index.html#mcp3008-single-ended
    # https://docs.circuitpython.org/projects/mcp3xxx/en/stable/api.html#adafruit_mcp3xxx.analog_in.AnalogIn
    # chan_0.value = Returns the value of an ADC pin as an integer. Due to 10-bit accuracy of the chip, the returned values range [0, 65472].
    # chan_0.voltage = Returns the voltage from the ADC pin as a floating point value. Due to the 10-bit accuracy of the chip, returned values range from 0 to (reference_voltage * 65472 / 65535)
    # DAQ max value is 65472

    import adafruit_mcp3xxx.mcp3008 as MCP
    import board
    import busio
    import digitalio
    from adafruit_mcp3xxx.analog_in import AnalogIn

    spi = busio.SPI(clock=board.SCK, MISO=board.MISO, MOSI=board.MOSI)
    cs = digitalio.DigitalInOut(board.D5)  # GPIO pin 5
    mcp = MCP.MCP3008(spi, cs, ref_voltage=5)  # 5 Volts
    chan_0 = AnalogIn(mcp, MCP.P0)  # MCP3008 pin 0

    # Setup connection for reading the flow sensor as a switch
    # https://gpiozero.readthedocs.io/en/stable/api_input.html?highlight=Button#gpiozero.Button
    # Note, I would prefer to read the pulses per minute with RPi.GPIO as in fan_control.py,
    # but my flow sensor only produces a constant Vcc while flow is occurring, no pulses.
    from gpiozero import Button
    from gpiozero.pins.rpigpio import RPiGPIOFactory

    def rise() -> None:
        """Flow sensor rise action."""
        global had_flow
        had_flow = 1

    def fall() -> None:
        """Flow sensor fall action."""
        global had_flow
        had_flow = 0

    # bounce_time and hold_time are in seconds
    factory = RPiGPIOFactory()
    flow_switch = Button(pin=19, pull_up=False, bounce_time=0.1, hold_time=1, pin_factory=factory)
    flow_switch.when_held = rise
    flow_switch.when_released = fall

    # Setup connection to i2c display
    # https://luma-oled.readthedocs.io/en/latest
    if DISPLAY_OLED:
        from luma.core.error import DeviceNotFoundError
        from luma.core.interface.serial import i2c
        from luma.core.render import canvas
        from luma.oled.device import sh1106
        from PIL import ImageFont

        i2c_device = sh1106(i2c(port=1, address=0x3C), rotate=0)

        try:
            OLED_FONT_SIZE = 14  # pylint: disable=invalid-name
            OLED_FONT = ImageFont.truetype(  # pylint: disable=invalid-name
                "DejaVuSans.ttf", size=OLED_FONT_SIZE
            )
        except OSError:
            OLED_FONT_SIZE = 12  # pylint: disable=invalid-name
            # ImageFont and FreeTypeFont behave the same in draw.text()
            OLED_FONT = ImageFont.load_default()  # type: ignore[assignment] # pylint: disable=invalid-name
        except Exception as error_oled_font:
            my_print(
                f"Unexpected error in ImageFont:\n{error_oled_font = }\n{type(error_oled_font) = }\n{traceback.format_exc()}\nExiting!",
                logger_level=logging.ERROR,
            )
            sys.exit(1)

        def paint_oled(
            lines: list[str],
            *,
            lpad: float = 4.0,
            vpad: float = 0.0,
            line_height: int = OLED_FONT_SIZE,
            bounding_box: bool = False,
        ) -> None:
            """Function to paint OLED display.

            Args:
                lines (list[str]): List of strings to be printed.
                lpad (float): Screen left pad. (Default value = 4.0)
                vpad (float): Screen top vertical pad. (Default value = 0.0)
                line_height (int): Line height. (Default value = OLED_FONT_SIZE)
                bounding_box (bool): Flag for including an outline bounding box. (Default value = False)
            """
            try:
                with canvas(i2c_device) as draw:
                    if bounding_box:
                        draw.rectangle(i2c_device.bounding_box, outline="white", fill="black")

                    for i_line, line in enumerate(lines):
                        draw.text(
                            (lpad, vpad + i_line * line_height),
                            line,
                            fill="white",
                            font=OLED_FONT,
                        )
            except (OSError, DeviceNotFoundError, TypeError):
                # do not log device not connected errors, OLED power is probably just off
                my_print(
                    line="",
                    logger_level=None,
                    use_print=False,
                )
                pass
            except Exception as error:
                # don't want to kill the DAQ just because of an OLED problem
                my_print(
                    f"Unexpected error in paint_oled():\n{error = }\n{type(error) = }\n{traceback.format_exc()}\nContinuing",
                    logger_level=logging.DEBUG,
                    use_print=False,
                )
                pass

    # Setup web page
    # following https://github.com/donskytech/dht22-weather-station-python-flask-socketio
    if DISPLAY_WEB:
        import json

        import python_arptable
        from flask import Flask, render_template, request
        from flask_socketio import SocketIO

        flask_app = Flask(
            __name__,
            static_url_path="",
            static_folder=str(pathlib.Path("web", "static")),
            template_folder=str(pathlib.Path("web", "templates")),
        )

        # pragma: allowlist nextline secret
        flask_app.config["SECRET_KEY"] = "test"  # nosec: B105
        flask_app.config["TEMPLATES_AUTO_RELOAD"] = True

        logger_sio = logging.getLogger("sio")
        logger_sio.setLevel(logging.WARNING)
        if 1 < VERBOSITY:
            logger_sio.setLevel(logging.DEBUG)

        if LOG_TO_FILE:
            logger_sio.addHandler(logging_fh)

        sio = SocketIO(
            flask_app,
            cors_allowed_origins="*",
            logger=logger_sio,
            engineio_logger=logger_sio,
        )

        @flask_app.route("/")
        def index() -> str:
            """Serve index.html.

            Returns:
                str: Rendered template.
            """
            try:
                return render_template("index.html")
            except Exception as error:
                # don't want to kill the DAQ just because of a web problem
                my_print(
                    f"Unexpected error in index():\n{error = }\n{type(error) = }\n{traceback.format_exc()}\nContinuing",
                    logger_level=logging.DEBUG,
                    use_print=False,
                )
                return ""

        def conn_details() -> str:
            """Get connection details.

            Session ID, IP address and MAC address.

            Returns:
                str: Connection details.
            """
            try:
                ip_address = request.remote_addr
                mac_address = "Unknown"
                for _ in python_arptable.get_arp_table():
                    if _.get("IP address") == ip_address:
                        mac_address = _.get("HW address", mac_address)
                        break

                conn_details_str = (
                    f"sid: {request.sid}"  # type: ignore[attr-defined]
                    + f", IP address: {ip_address}"
                    + f", MAC address: {mac_address}"
                )

            except Exception as error:
                # don't want to kill the DAQ just because of a web problem
                my_print(
                    f"Unexpected error in conn_details():\n{error = }\n{type(error) = }\n{traceback.format_exc()}\nContinuing",
                    logger_level=logging.DEBUG,
                    use_print=False,
                )
                conn_details_str = "ERROR"

            return conn_details_str

        @sio.on("connect")
        def connect() -> None:
            """Decorator for connect."""
            try:
                global new_connection
                new_connection = True
                my_print(
                    f"Client connected {conn_details()}",
                    use_print=DISPLAY_TERMINAL and DISPLAY_WEB_LOGGING_TERMINAL,
                )
            except Exception as error:
                # don't want to kill the DAQ just because of a web problem
                my_print(
                    f"Unexpected error in connect():\n{error = }\n{type(error) = }\n{traceback.format_exc()}\nContinuing",
                    logger_level=logging.DEBUG,
                    use_print=False,
                )
                pass

        @sio.on("disconnect")
        def disconnect() -> None:
            """Decorator for disconnect."""
            try:
                my_print(
                    f"Client disconnected {conn_details()}",
                    use_print=DISPLAY_TERMINAL and DISPLAY_WEB_LOGGING_TERMINAL,
                )
            except Exception as error:
                # don't want to kill the DAQ just because of a web problem
                my_print(
                    f"Unexpected error in disconnect():\n{error = }\n{type(error) = }\n{traceback.format_exc()}\nContinuing",
                    logger_level=logging.DEBUG,
                    use_print=False,
                )
                pass

        if not (0 < VERBOSITY or DISPLAY_WEB_LOGGING_TERMINAL):
            # No messages in terminal
            import flask.cli

            flask.cli.show_server_banner = lambda *args: None  # noqa: U100

        # never write werkzeug logs to terminal
        log_werkzeug = logging.getLogger("werkzeug")
        log_werkzeug.setLevel(logging.WARNING)
        if 0 < VERBOSITY:
            log_werkzeug.setLevel(logging.DEBUG)

        if LOG_TO_FILE:
            log_werkzeug.addHandler(logging_fh)

        t_local_str_n_last: list[str] = []
        mean_pressure_value_normalized_n_last: list[float] = []
        past_had_flow_n_last: list[int] = []

        def get_ip_address() -> str:
            """Get IP address of host machine.

            https://stackoverflow.com/a/28950776

            Returns:
                str: IP address of host.
            """
            m_socket = socket.socket(socket.AF_INET, socket.SOCK_DGRAM)
            m_socket.settimeout(0)
            try:
                # doesn't even have to be reachable
                m_socket.connect(("10.254.254.254", 1))
                ip_address = m_socket.getsockname()[0]
            except Exception:
                ip_address = "127.0.0.1"
            finally:
                m_socket.close()

            return ip_address

        PORT_NUMBER: Final = 5000  # pylint: disable=invalid-name
        host_ip_address = get_ip_address()

    # Wait until UTC minutes is mod STARTING_TIME_MINUTES_MOD
    # Then if the script is interrupted, we can resume on the same cadence
    t_start = datetime.datetime.now(UTC_TIMEZONE)
    t_start_minute = (
        t_start.minute - (t_start.minute % STARTING_TIME_MINUTES_MOD) + STARTING_TIME_MINUTES_MOD
    ) % 60

    t_start = t_start.replace(minute=t_start_minute, second=0, microsecond=0)

    t_utc_str = t_start.astimezone(UTC_TIMEZONE).strftime(DATETIME_FMT)
    t_local_str = t_start.astimezone(LOCAL_TIMEZONE).strftime(DATETIME_FMT)

    if LOG_TO_FILE:
        my_print(f"Logging to {FNAME_LOG}", print_prefix="\n")

    if DISPLAY_WEB:
        my_print(
            f"Live dashboard hosted at: http://{host_ip_address}:{PORT_NUMBER}",
            print_prefix="\n",
        )

    my_print(
        f"Starting DAQ at {t_utc_str} UTC, {t_local_str} {LOCAL_TIMEZONE_STR}",
        print_prefix="\n       ",
    )
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

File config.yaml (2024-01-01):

general:
  # Set 0% and 100% normalized pressure values
  observed_pressure_min: 5500
  observed_pressure_max: 13600
  # Repo location
  package_path: "~/chance_of_showers"
  # Datetime settings
  date_fmt: "%Y-%m-%d"
  time_fmt: "%H:%M:%S"
  fname_datetime_fmt: "%Y-%m-%d-%H-%M-%S"
  local_timezone: "US/Eastern"
  random_seed: 42
daq:
  # Display options
  log_to_file: true
  display_terminal: true
  display_terminal_overwrite: true
  display_oled: true
  display_web: true
  display_web_logging_terminal: false
  verbosity: 0
  # DAQ parameters
  starting_time_minutes_mod: 1
  averaging_period_seconds: 60
  polling_period_seconds: 1
  raw_data_relative_path: "daq/raw_data"
  # Log parameters
  logs_relative_path: "daq/logs"
  log_memory_usage: false
  log_memory_usage_minutes_mod: 30
  # Web parameters
  n_last_points_web: 15
  # Historical development datetimes
  # When the issue of drifting seconds was fixed by
  # t_start = t_start.replace(minute=t_start_minute, second=0, microsecond=0)
  end_of_drifting_seconds: "2023-05-02 01:22:08"
  # When web threading was fixed, eliminating duplicate records from multiple threads
  end_of_threading_duplicates: "2023-05-31 04:36:00"
  # When sticking flow variable was fixed
  end_of_sticking_flow: "2023-05-15 04:00:00"
  # When cron job restarts and heartbeat monitoring was live
  start_of_cron_heartbeat_monitoring: "2023-07-26 00:00:00"
fan_control:
  # Print temperature, PWM, and RPM
  verbose: true
  # GPIO pins
  fan_pin: 18
  tach_pin: 23
  # Time to wait between each refresh
  refresh_period_seconds: 5
  # Fan parameters
  pulses_per_revolution: 2
  pwm_freq_khz: 25
  # Fan curve parameters
  min_temp: 35
  max_temp: 40
  fan_low: 30
  fan_high: 100
etl:
  saved_data_relative_path: "daq/saved_data"
ana:
  trainable_start_datetime_local: "2023-06-26 13:30:00"
  trainable_end_datetime_local: "2023-09-01 00:00:00"
  trainable_val_fraction: 0.25
# No hydra logging https://stackoverflow.com/a/70777327
defaults:
  - _self_
  - override hydra/hydra_logging: disabled
  - override hydra/job_logging: disabled
hydra:
  output_subdir: null
  run:
    dir: .

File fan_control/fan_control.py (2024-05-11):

"""PWM fan control for Raspberry Pi.

Adapted from https://blog.driftking.tw/en/2019/11/Using-Raspberry-Pi-to-Control-a-PWM-Fan-and-Monitor-its-Speed/
"""

import pathlib
import sys
import time
from typing import Final

import hydra
from omegaconf import DictConfig  # noqa: TC002

# pylint: disable=no-member
from RPi import GPIO

__all__: list[str] = []


# Setup global variables
current_time = time.time()
rpm = 0.0  # pylint: disable=invalid-name


@hydra.main(version_base=None, config_path="..", config_name="config")
def fan_control(cfg: DictConfig) -> None:
    """Run the fan control script.

    Args:
        cfg (DictConfig): Hydra configuration.
    """
    # Configuration
    # pylint: disable=invalid-name
    VERBOSE: Final = cfg["fan_control"]["verbose"]  # print temperature, PWM, and RPM

    FAN_PIN: Final = cfg["fan_control"]["fan_pin"]  # BCM pin used to drive PWM fan
    TACH_PIN: Final = cfg["fan_control"]["tach_pin"]  # Pin used to read the fan's tachometer signal

    REFRESH_PERIOD_SECONDS: Final = cfg["fan_control"][
        "refresh_period_seconds"
    ]  # Time to wait between each refresh

    PULSES_PER_REVOLUTION: Final = cfg["fan_control"][
        "pulses_per_revolution"
    ]  # Noctua fans puts out two pluses per revolution
    PWM_FREQ_KHZ: Final = cfg["fan_control"]["pwm_freq_khz"]  # 25kHz for Noctua PWM control

    # Fan curve parameters
    MIN_TEMP: Final = cfg["fan_control"]["min_temp"]
    MAX_TEMP: Final = cfg["fan_control"]["max_temp"]
    FAN_LOW: Final = cfg["fan_control"]["fan_low"]
    FAN_HIGH: Final = cfg["fan_control"]["fan_high"]
    FAN_MAX: Final = 100.0
    # pylint: enable=invalid-name

    # Lock script, avoid launching duplicates
    sys.path.append(str(pathlib.Path.cwd().parent))
    from utils.shared_functions import (  # pylint: disable=import-outside-toplevel
        get_lock,
        get_SoC_temp,
    )

    get_lock("fan_control")

    # Functions

    def set_fan_speed(speed: float) -> None:
        """Set fan speed.

        Args:
            speed (float): Desired fan speed, 0 to 100.
        """
        fan.start(speed)
        # Note that fan is defined later as GPIO.PWM(FAN_PIN, PWM_FREQ_KHZ)

    def fell(pin: int) -> None:  # noqa: U100 # pylint: disable=unused-argument
        """Fell action.

        Calculate pulse frequency and RPM.

        Args:
            pin (int): Unused, but needed to type annotation the callback of GPIO.add_event_detect().
        """
        global current_time
        global rpm

        delta_t = time.time() - current_time
        # Reject spuriously short pulses
        if 0.005 < delta_t:
            freq = 1 / delta_t
            rpm = (freq / PULSES_PER_REVOLUTION) * 60
            current_time = time.time()

    def handle_fan_speed() -> None:
        """Handle fan speed."""
        global rpm

        temp = get_SoC_temp()
        fan_commanded_speed = FAN_MAX

        # Set fan speed to FAN_LOW if the temperature is below MIN_TEMP
        if temp < MIN_TEMP:
            fan_commanded_speed = FAN_LOW

        # Set fan speed to FAN_MAX if the temperature is above MAX_TEMP
        elif temp > MAX_TEMP:
            fan_commanded_speed = FAN_MAX

        # Calculate dynamic fan speed
        else:
            step = (FAN_HIGH - FAN_LOW) / (MAX_TEMP - MIN_TEMP)
            fan_commanded_speed = FAN_LOW + step * round(temp - MIN_TEMP)

        # Set speed and display parameters
        set_fan_speed(fan_commanded_speed)

        if VERBOSE:
            sys.stdout.write(
                "\x1b[2K" + f"Temp: {temp:.1f}, PWM {0.01*fan_commanded_speed:.0%}, RPM {rpm:.0f}\r"
            )
            sys.stdout.flush()

        rpm = 0

    try:
        # Setup GPIO pins
        GPIO.setwarnings(False)
        GPIO.setmode(GPIO.BCM)

        GPIO.setup(TACH_PIN, GPIO.IN, pull_up_down=GPIO.PUD_UP)  # Pull up to 3.3V
        GPIO.setup(FAN_PIN, GPIO.OUT, initial=GPIO.LOW)

        fan = GPIO.PWM(FAN_PIN, PWM_FREQ_KHZ)
        set_fan_speed(FAN_MAX)

        # Add event to detect
        GPIO.add_event_detect(TACH_PIN, GPIO.FALLING, fell)

        # Handle fan speed every REFRESH_PERIOD_SECONDS sec
        while True:
            handle_fan_speed()
            time.sleep(REFRESH_PERIOD_SECONDS)

    except KeyboardInterrupt:  # trap a CTRL+C keyboard interrupt
        set_fan_speed(FAN_MAX)
        GPIO.cleanup()  # resets all GPIO ports used by this function


if __name__ == "__main__":
    fan_control()  # pylint: disable=no-value-for-parameter

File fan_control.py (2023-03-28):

# Adapted from https://blog.driftking.tw/en/2019/11/Using-Raspberry-Pi-to-Control-a-PWM-Fan-and-Monitor-its-Speed/

import RPi.GPIO as GPIO
import time
import signal
import sys, os

# Configuration
verbose = True  # print temp, PWM, RPM
FAN_PIN = 18  # BCM pin used to drive PWM fan
TACH_PIN = 23  # Fan's tachometer output pin
WAIT_TIME = 5  # [s] Time to wait between each refresh
PULSE = 2  # Noctua fans puts out two pluses per revolution
PWM_FREQ = 25  # [kHz] 25kHz for Noctua PWM control

# Configurable temperature and fan speed
MIN_TEMP = 35
MAX_TEMP = 50
FAN_LOW = 30
FAN_HIGH = 100
FAN_OFF = 0
FAN_MAX = 100

# Setup variables
t = time.time()
rpm = 0


# Get CPU's temperature
def getCpuTemperature():
    res = os.popen("vcgencmd measure_temp").readline()
    temp = float(res.replace("temp=", "").replace("'C\n", ""))

    return temp


# Set fan speed
def setFanSpeed(speed):
    fan.start(speed)

    return None


# Caculate pulse frequency and RPM
def fell(n):
    global t
    global rpm

    dt = time.time() - t
    if dt < 0.005:
        return None  # Reject spuriously short pulses

    freq = 1 / dt
    rpm = (freq / PULSE) * 60
    t = time.time()


# Handle fan speed
def handleFanSpeed():
    global rpm

    temp = getCpuTemperature()
    fan_commanded_speed = FAN_MAX

    # Turn off the fan if temperature is below MIN_TEMP
    if temp < MIN_TEMP:
        fan_commanded_speed = FAN_OFF

    # Set fan speed to MAXIMUM if the temperature is above MAX_TEMP
    elif temp > MAX_TEMP:
        fan_commanded_speed = FAN_MAX

    # Caculate dynamic fan speed
    else:
        step = (FAN_HIGH - FAN_LOW) / (MAX_TEMP - MIN_TEMP)
        fan_commanded_speed = FAN_LOW + step * round(temp - MIN_TEMP)

    # Set speed and display parameters
    setFanSpeed(fan_commanded_speed)

    if verbose:
        sys.stdout.write(
            "\x1b[2K"
            + f"Temp: {temp:.1f}, PWM {0.01*fan_commanded_speed:.0%}, RPM {rpm:.0f}\r"
        )
        sys.stdout.flush()

    rpm = 0

    return None


try:
    # Setup GPIO pins
    GPIO.setwarnings(False)
    GPIO.setmode(GPIO.BCM)

    GPIO.setup(TACH_PIN, GPIO.IN, pull_up_down=GPIO.PUD_UP)  # Pull up to 3.3V
    GPIO.setup(FAN_PIN, GPIO.OUT, initial=GPIO.LOW)

    fan = GPIO.PWM(FAN_PIN, PWM_FREQ)
    setFanSpeed(FAN_OFF)

    # Add event to detect
    GPIO.add_event_detect(TACH_PIN, GPIO.FALLING, fell)

    # Handle fan speed every WAIT_TIME sec
    while True:
        handleFanSpeed()
        time.sleep(WAIT_TIME)

except KeyboardInterrupt:  # trap a CTRL+C keyboard interrupt
    setFanSpeed(FAN_HIGH)
    GPIO.cleanup()  # resets all GPIO ports used by this function

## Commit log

2023-03-28 PWM fan control with RPM reading
2023-05-02 normalize pressure by min and max, add header to csv, clean up variable names, exit gracefully, clean up print statements
2023-05-02 Set seconds to 0 at start of polling loop to avoid drift over multiple hours / days
    [daq.py]
2023-05-09 added switch_test
2023-05-09 Upgraded DAQ script
    - Now includes flow measurements
    - Improved wait to start with pause package
    - Print start time in advance
    - Upgraded OLED display screens
    - Removed per value min/max record keeping, use min/max of means per polling period in analysis instead
    - Set normalizing params to round numbers
2023-05-09 revert to 1 min
    [daq.py]
2023-05-14 Reset had_flow each averaging period
    Noticed that the flow sensor can get stuck in a high position,
    possibly when the pressure goes to zero?
    This should help avoid stuck high readings,
    but the flow sensor is probably still unreliable.
    [daq.py]
2023-05-27 OLED display issues will not kill DAQ
    [daq.py]
2023-06-12 Web Display (#1)
    * setup needed packages for web
    * Setup flask_socketio
    Switches for terminal and OLED displays
    * mvp webpage
    * fix mod 60 error if starting at xx:59
    * style
    * sio match package doc
    * more plots
    * style
    * raspberry pi faviocon
    * send past n_last mean values as arrays
    * bug fix
    * fixed 0 flow data yesterday
    * better updating logic, layout
    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
    [daq.py]
2023-07-03 ETL v0.0 (#4)
    * added polars
    * move polars to daq
    * poetry move
    * poetry update
    * added hydra
    * hydra config
    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
2023-07-04 Use running_daq_loop to avoid saving partial row (#5)
    [daq.py]
2023-07-11 CI improvements:
    - Switch to local poetry run calls in tests.yml to better use cache
    - Cleaned up noqa tags
    - Added make find_noqa_comments to grep all noqa tags
    - Added make vulture-update_ignore to update vulture ignore file
    - Added make blocklint
    - Added blocklint excludes, threshold
    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
2023-07-12 Hydra DAQ script config (#8)
    * Migrated configs to hydra
    * Made local timezone configurable
    * Don't print commented out command
    * Change hydra to use the compose_api
    Can not set config via CLI, which is fine, but do not need to use the __main__ app() construct.
    https://hydra.cc/docs/advanced/compose_api/
2023-07-14 Wait until we have a mean pressure value before starting the web server
    Hopefully this will help avoid intermittent crashes in the flask code that happen when the DAQ has just been started.
    [daq.py]
2023-07-18 Move common code into `utils` (#13)
    * Created shared_functions.py
    * created utils dir
    * Use utils in fan control as a test
    * Use utils in daq.py
    * Fix type annotation
    * Change pylint disables to full names
    * Updated notebook
    * Exclude .ipynb_checkpoints from linting
    * Exclude ana/*.py from lint
    * mypy
    * remove .py
    * Standardize lint ignore, add pylint
    * Remove _FLOW
    * update etl output fname
    [daq.py, etl.py, fan_control.py]
2023-07-19 Bug fixes (#15)
    * added missing f strings
    * Change logging to use UTC
    * added yamllint to find_noqa_comments
    * Turn off print for memory log calls
    [daq.py]
2023-07-29 Hydra v2 (#19)
    * Added hydra to fan_control
    * Add fan_control to start_daq
    * Added Final type annotation and upper case names
    for constant variables
    * Very aggressive fan curve
    * Added Final type annotation and upper case names
    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
2023-08-09 Ana v0.0.0 (#20)
    * updated packages
    * Switch to using .py notebook via jupytext
    * updated for linting .py notebooks
    * fix stats
    * update per file ignores
    * lint notebook
    * improve pre-commit for pylint
    * only run on changed files with make pre-commit
    * updated plotly time series plot
    * Added histogram
    * vulture exclude files
    * split up pre-commit commands
    * Added reference lines for hists
    * Added max and min reference lines
    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
    [config.yaml, daq.py, etl.py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]
2023-08-24 Prophet v0.0.0 (#21)
    * Added prophet as a dependency
    * Added C_GREEN
    * Added trainable_start_datetime_local reference line and cut for training data
    Started prophet section
    * Added ipywidgets for notebook progress bars
    * Initial prophet model
    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
2023-10-19 clean up prints
2023-11-14 DAQ Tweaks (#25)
    * Try not pre-allocating the arrays
    * Add holidays as dep for all groups
    * update hash
    * move pandas
    * Updated poetry lock
    * Remove commented out code
    Note, this might need to be reversed later, depending on which method used less memory
    * Added --no-root option for poetry install
    * Fix poetry python versions
    [daq.py]
2023-12-03 Improve Documentation (#26)
    * Adding web dashboard demo video
    Converted from screen-capture.mp4 with the following settings
    ffmpeg -i screen-capture.mp4 -hide_banner -t 00:01:21.5 -c:v libx264 -crf 36 -r 8 -an chance_of_showers_dashboard_demo.mp4
    https://itsfoss.com/ffmpeg/
    * Try embedding video in README via relative path
    * Test embedding methods
    * Test embedding methods
    * Change centering and video settings
    * Change video settings
    * without type
    * revert
    * Remove html attributes that github is not rendering
    * Clean comments
    * Worked on README, WIP
    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
    [circuit_diagram.kicad_pcb, circuit_diagram.kicad_sch]
2023-12-17 Improve Documentation (#27)
    * Try relative link to mp4
    * Revert relative path
    * Try relative jpg
    * Fix typo
    * Test table of images
    * Table formatting
    * link all jpg
    * Rename
    * Fix typo
    * Final touches on circuit diagram
    Save pdf and svg
    * Update README for circuit diagram
    * edit README
    * Update svg
    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
    [circuit_diagram.kicad_sch]
2023-12-18 Add Prophet via darts wrapper (#28)
    * Update mypy
    * Update jupyterlab
    * Start adding ProphetWrapper class
    * Use pad interpolation if rebinning y
    Add verbose to model wrapper class
    * Clean up notebook
    * Update packages for dependabot
    * Remove sudo
    * Add plotly to html code for Prophet
    * Use pathlib instead of os
    * Comment out Stopping Here in notebook for CI
    * Fix bugs
    * Add ProphetWrapper
    * Use pathlib instead of os
    [daq.py, etl.py, fan_control.py]
2023-12-18 DAQ Restore Pre-allocation (#29)
    * Restore the pre-allocation of numpy arrays in DAQ script.
    Reverts https://github.com/mepland/chance_of_showers/pull/25 after memory usage testing.
    See pre_allocation_test_results.md for full results.
    * markdownlint
    [daq.py]
2024-01-01 Improve plotting (#34)
    * Import plotting last to avoid rcParams being reset
    Check OBSERVED_PRESSURE_MIN value
    Improve legend for plotly plots
    * Update rcParams
    Add ref lines to plotly legend
    * Update observed_pressure_min
    * Save plotly to html
    * Work on plots
    * Change to outputs
    * Add function to cleanly plot prophet figures
    * Clean up prophet plots
    * Add start_of_cron_heartbeat_monitoring
    * Complete DAQ stats calc
    * Remove native prophet code, now that the darts wrapper has surpassed it.
    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
    [config.yaml, daq.py, etl.py]
2024-01-20 Added more Darts models (#38)
    * Split wrappers into their own files, added N-HiTS
    * Clean up notebook and flake8 config
    * Remove powerline
    * Update gitpython for dependabot
    * Update jinja2 for dependabot
    * Started TCN
    * Add random_state for NN darts models
    * disable duplicate code checks for subclasses, __int__ needs to be written out like this
    * Reorg
    * More duplicate code
    * Add TransformerModel
    * Added TFT
    * Added DLinear
    * Fix dropped params
    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
2024-02-04 Better exceptions in Bayesian opt (#47)
    * Abort iteration if max_time_per_model is exceeded
    Also handle keyboard interrupts better
    * bug fix AutoARIMA
    * touch up for debugging
    * Add all model wrappers
    * Need to convert to int here, before testing on next line
    * Do not duplicate points unnecessarily
    * Fix typing false positive
    * -inf no longer works, try a very negative number instead.
    * 10 seconds should be enough to wrap up a failed iter
    * Change bad_target to -999 to avoid sklearn errors
    * Change back to m = 1
    * Add accelerator option, split set_ funcs
    * accel = auto
    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
2024-02-19 Lint upgrades (#51)
    * Add pandas-vet linting
    * pandas-vet linting fixes
    * Added flake8-all-not-strings
    * Added flake8-absolute-import
    * Added flake8-assertive
    * Added flake8-broken-line
    * Added flake8-class-attributes-order
    * Added flake8-clean-block
    * Added flake8-comments
    * Added flake8-coding
    * Added flake8-dunder-all
    * Added flake8-functions-names
    * Added flake8-use-fstring, flake8-use-pathlib
    * Added flake8-slots, flake8-strftime
    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
2024-03-09 Update packages (#55)
    * Updated darts to 0.28.0
    https://github.com/unit8co/darts/blob/master/CHANGELOG.md#0280-2024-03-05
    * Update pre-commits
    * Update packages with poetry add pack@latest -G group
    * lint
    * lint
    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
2024-03-10 Spelling (#56)
    * Add typos and proselint to -G dev
    * Less poetry runs
    * Configure typos
    * Add typos to Makefile
    * Spelling corrections
    * Add typos to pre-commit
    * Working typos in pre-commit
    * fix poetry in pre-commit
    * Add typos-fix to Makefile
    * Test typo action
    * Should fail
    * Test continue-on-error
    * finalize typos action
    * update names
    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
    [daq.py, fan_control.py]
2024-05-01 Raspberry Pi DAQ Repair (#60)
    * Make dev optional
    * update packages
    * Turn off crashing RPiGPIOFactory
    * Comment out crashing fan_control
    * minor edits to README
    * Update polars syntax
    * Update polars
    * Re-enable gpio
    * Updated README
    [etl.py]
2024-05-03 Backup data to USB drive in heartbeat script (#61)
    * Backup data to USB drive in heartbeat script
    * mv section in README
    * Fix blacken-docs action filter
    * Remove extra $ char
2024-05-11 Linting Improvements (#62)
    * Updated Makefile
    - Clean up `git ls-file` commands, add ipynb as python file type
    - Always return success for grep commands
    - Add `find_double_spaces`
    * Added ipynb as python file type
    * Use use google style doc strings
    * Add ruff as optional linter, only via Makefile
    Will be used to test ruff against flake8, and use ruff's fix functionality.
    https://docs.astral.sh/ruff/linter
    * Add more ruff commands
    * Added pymend for docstring auto fixing
    * require type hints in docstrings
    * Lint docstrings
    * sync exclude
    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
    [daq.py, etl.py, fan_control.py]
2024-05-21 Infra improvements (#69)
    * Specify python3.11 in setup
    * Run all tests even if prior tests fail
    * Reorder pyupgrade after isort
    * Add log2ram to README
    * Add trailing-spaces check
    * find trailing spaces in Makefile
    * Always print filenames via H
    * Fix double space

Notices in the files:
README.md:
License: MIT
